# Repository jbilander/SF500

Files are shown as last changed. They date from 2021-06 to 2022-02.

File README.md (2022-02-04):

# SF500
Spitfire 500, A low-end 14 MHz Accelerator with IDE and 4/8 MB fast RAM for the Amiga 500.
***
Heavily inspired by Matthias Heinrichs' CDTV-RAM-IDE board. Many thanks to Matze for sharing his work and letting me open source this project.

https://gitlab.com/MHeinrichs/CDTV-RAM-IDE/

Please note, if you are going to build boards and sell for profit, you will need a consent from Matthias and also from Oliver Kastl if you are going to bundle this software http://aminet.net/package/disk/misc/oktapus with the hardware (ROM-chip).

***

<a href="images/SF500_rev1b_pic1.jpg">
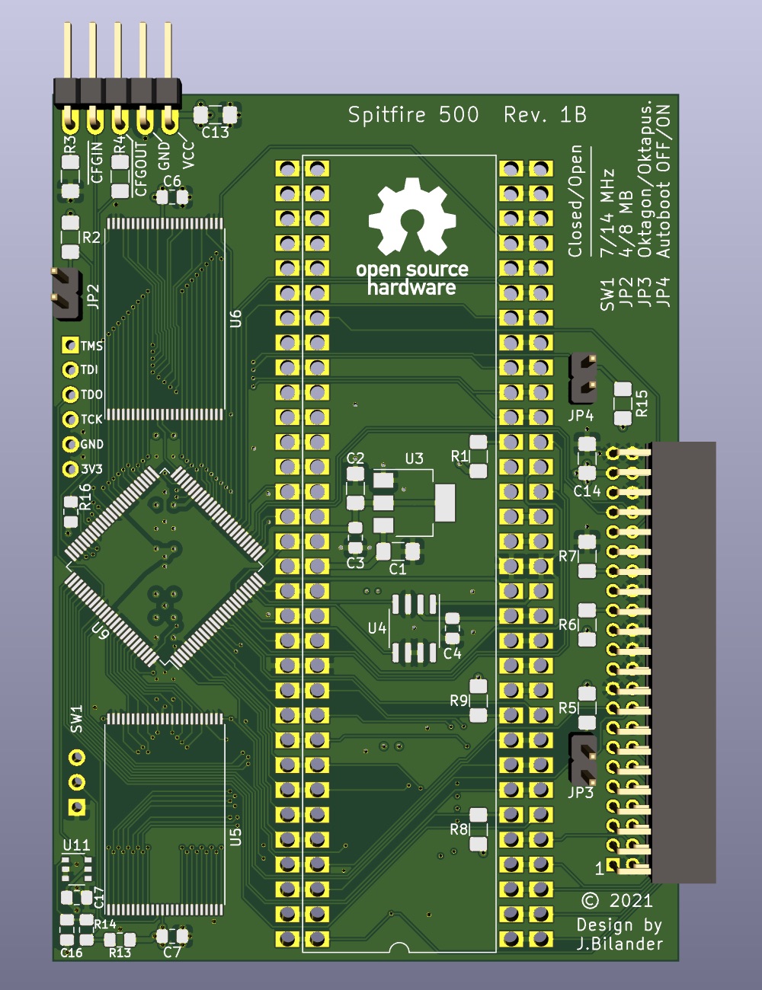
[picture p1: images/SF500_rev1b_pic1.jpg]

</a>
<a href="images/SF500_rev1b_pic2.jpg">
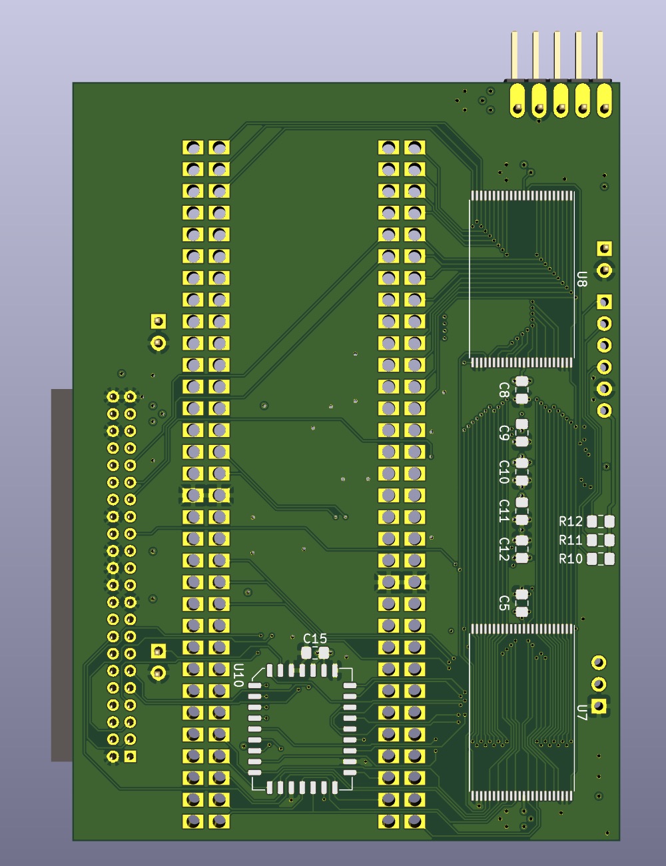
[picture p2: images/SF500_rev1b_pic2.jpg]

</a>

    Board is four layers:
    
    signal (with 3V3-zone)
    power plane (GND)
    power plane (VCC)
    signal

***

Rev. 1B installed in an A500. The 7/14 MHz switch can be easily accessed if hanging out the sidecar port opening of the A500 case. This switch can also be switched while the machine is running.

***

<a href="images/SF500_rev1b_pic3.jpg">
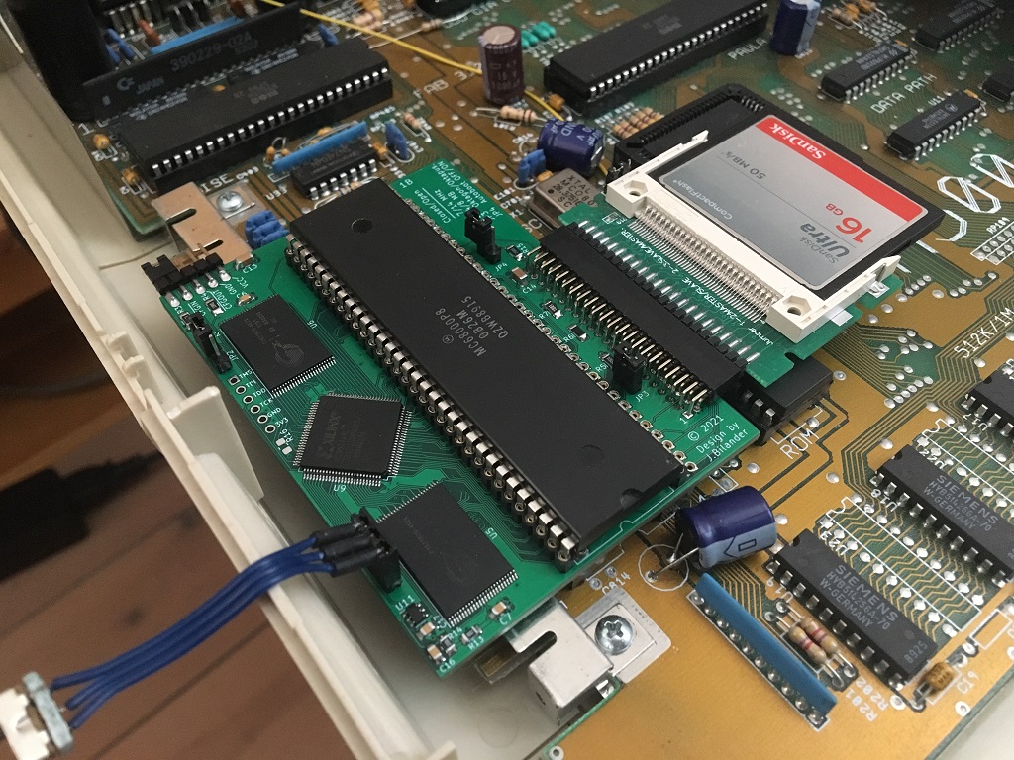
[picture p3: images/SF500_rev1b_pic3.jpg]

</a>
<a href="images/SF500_rev1b_pic4.jpg">
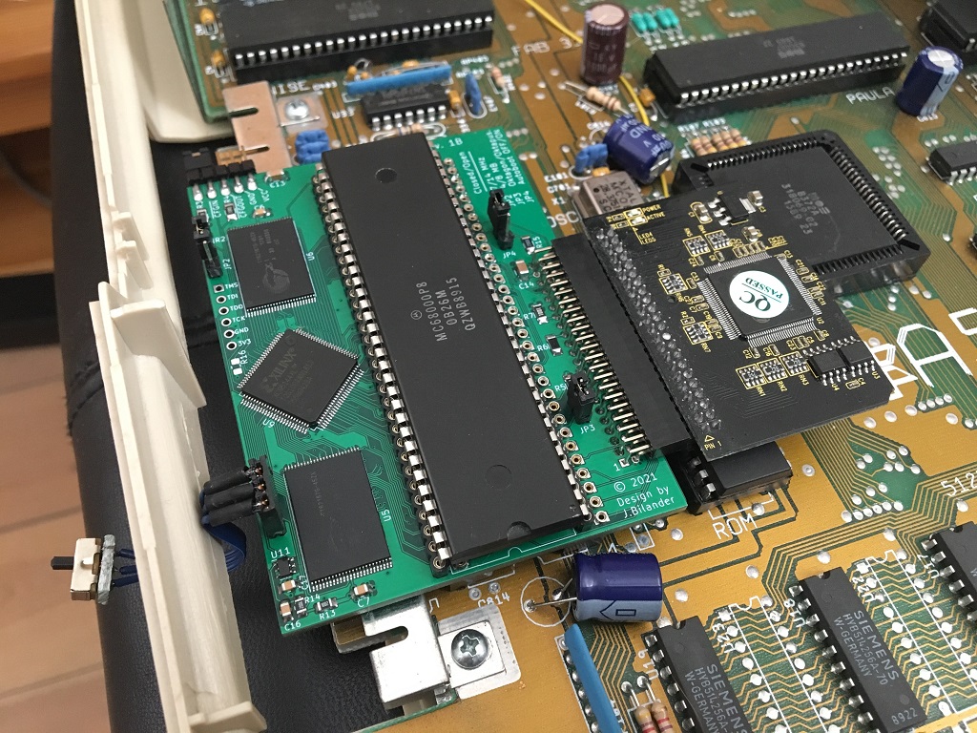
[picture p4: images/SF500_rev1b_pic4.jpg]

</a>

***

Videos: <br /><br />
https://drive.google.com/file/d/1c2K9_kcEqxMMBJBd1aELfbt1fV5XXoU6/view?usp=sharing

SysInfo tests running _oktagon.device_ on WB 1.3 on KS 1.3: <br />
https://drive.google.com/file/d/1rewl8bivpIMPoLze_-Y7_mGYqzTiX6ET/view?usp=sharing

Cold boot running _oktagon.device_ and WB 1.3 on KS 1.3: <br />
https://drive.google.com/file/d/1MFdxnaCo8lNMqMQ6eJMtNUMSsBB8mtb-/view?usp=sharing

Cold boot running _scsi.device v109.3_  (oktapussy) and ClassicWB 3.1 (with 1.3 theme) on KS 3.1: <br />
https://drive.google.com/file/d/1IrmWWG6SJgc65BBj8jGnHebKbp6LAcYa/view?usp=sharing

***

The CPU and the speed-select switch clears the A500 keyboard nicely when installed. Also the CF- or SD-card adapter clears the ROM-chip nicely.

***

<a href="images/SF500_rev1b_pic5.jpg">
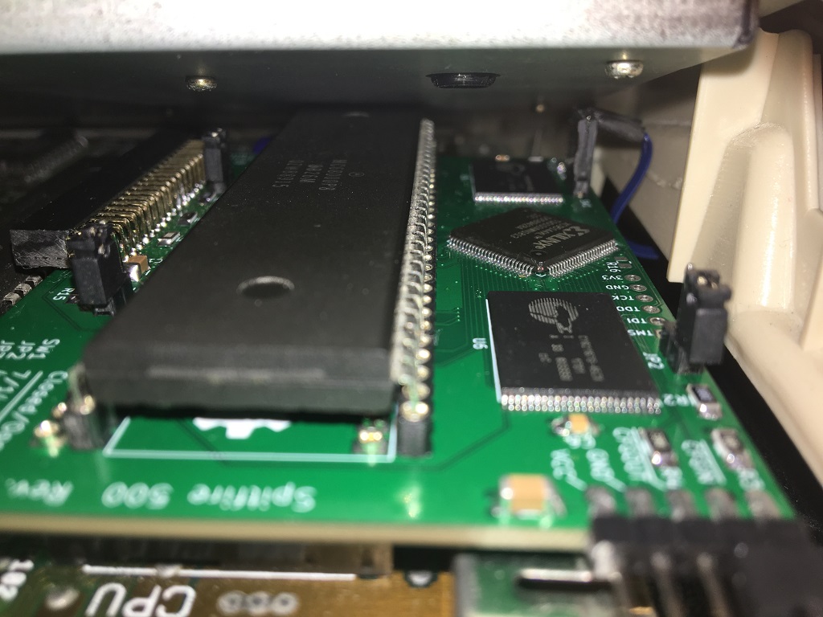
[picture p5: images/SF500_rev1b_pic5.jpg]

</a>
<a href="images/SF500_rev1b_pic6.jpg">
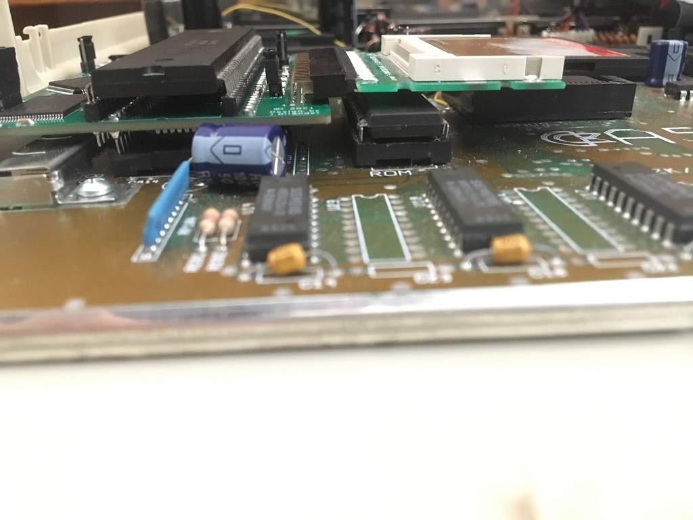
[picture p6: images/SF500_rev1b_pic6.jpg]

</a>

***

### Performance

14 MHz and JP3 Open (scsi.device v109.3):

<a href="images/SF500_rev1b_pic7.jpg">
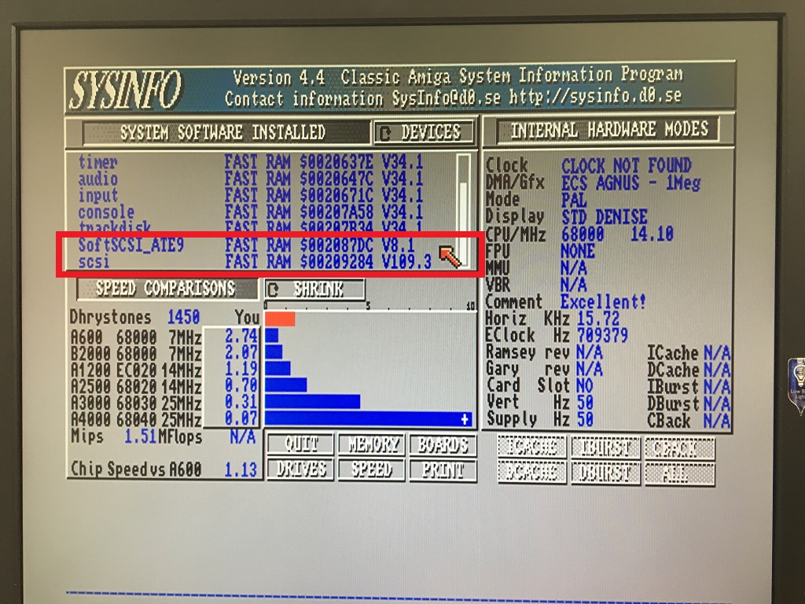
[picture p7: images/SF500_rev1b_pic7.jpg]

</a>
<a href="images/SF500_rev1b_pic9.jpg">
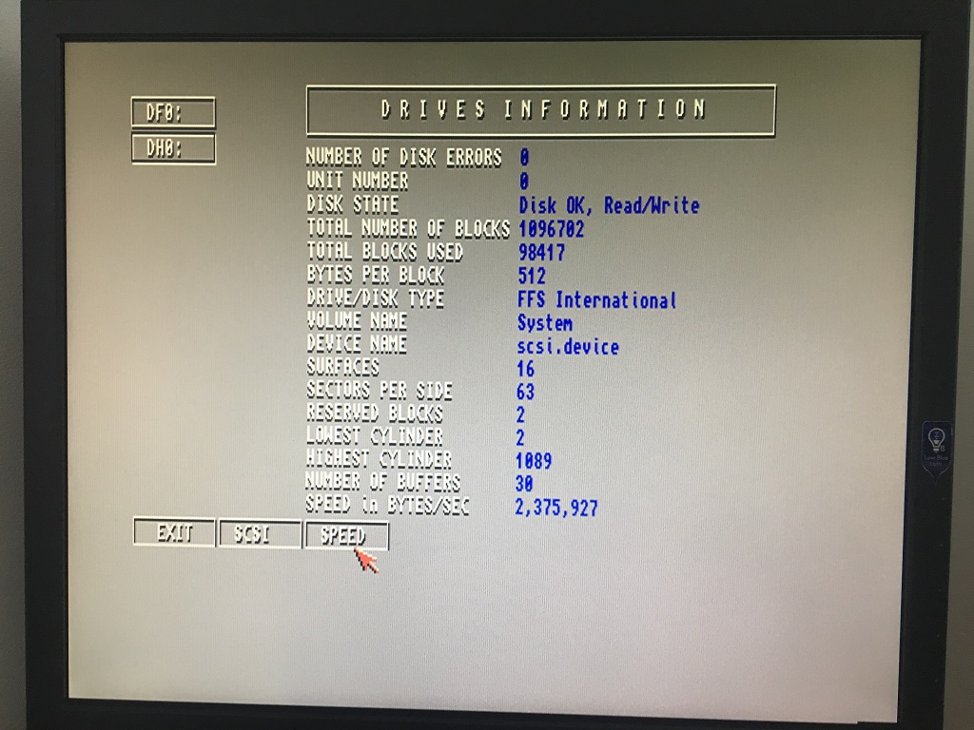
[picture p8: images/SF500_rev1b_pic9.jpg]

</a>

<br />
<br />

14 MHz and JP3 Closed (oktagon.device v6.10):

<a href="images/SF500_rev1b_pic8.jpg">
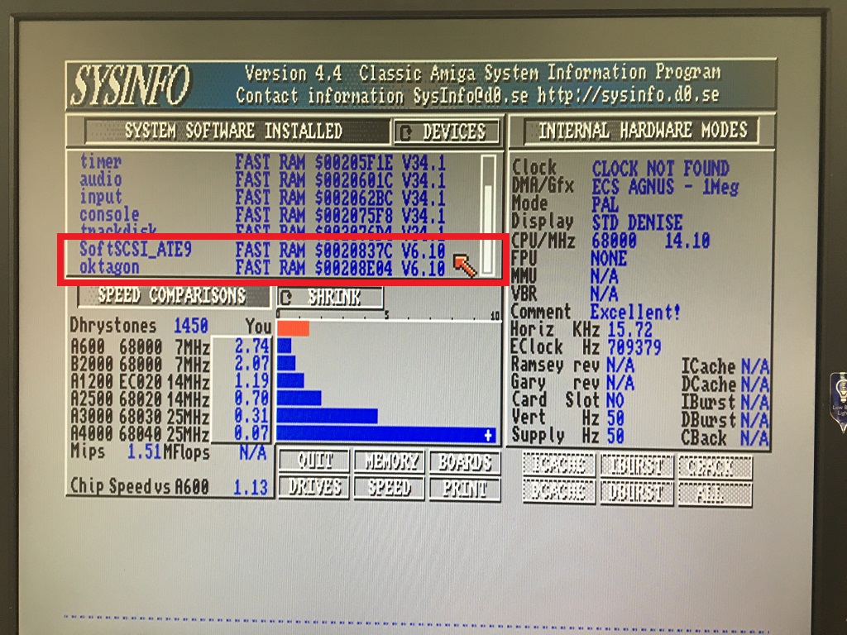
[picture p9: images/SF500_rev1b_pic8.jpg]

</a>
<a href="images/SF500_rev1b_pic10.jpg">
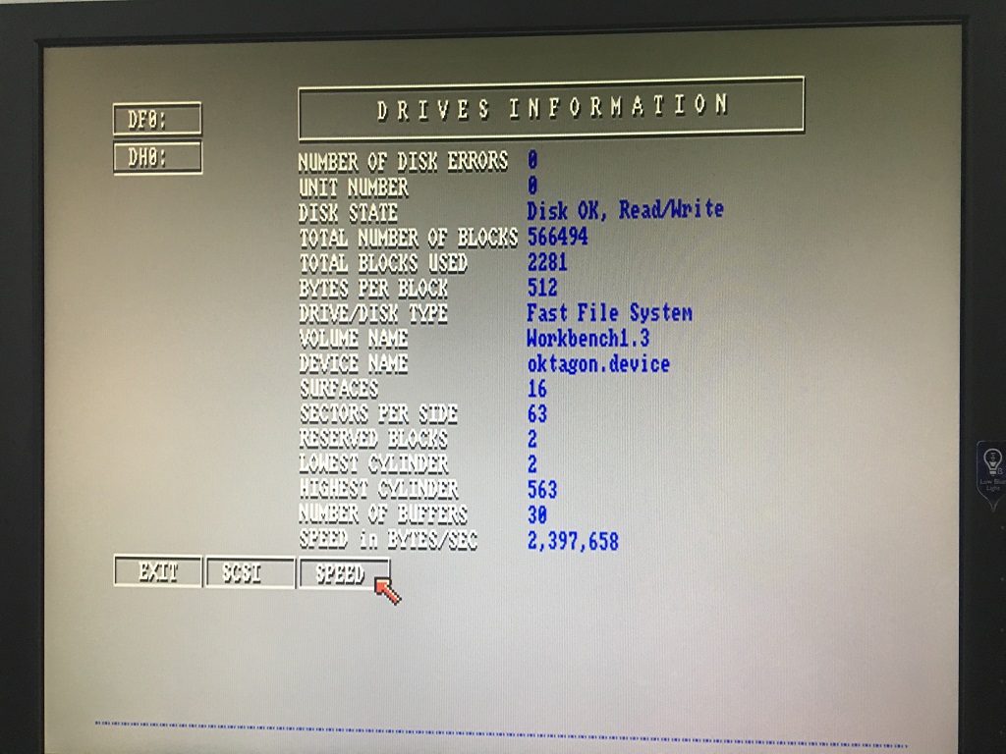
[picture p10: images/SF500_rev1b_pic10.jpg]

</a>

***

Keep in mind Kickstart 1.3 does not have FFS (Fast File System) in ROM, 
so in order to use FFS with 1.3 make a small boot-partition (e.g. ~200 MB) and format it DOS\1, 
not International (DOS\3) or DirCache (DOS\5), and not OFS (DOS\0). For KS 3.1 I would format it FFS International (DOS\3) or perhaps use PFS3. <br /><br />
https://en.wikipedia.org/wiki/Amiga_Fast_File_System <br />

Also, do not forget to set the MaxTransfer to _0x1fe00_ and hit Enter button after typing, then save the setting. This applies to all versions except the new KS 3.2

<a href="images/SF500_rev1b_pic11.jpg">
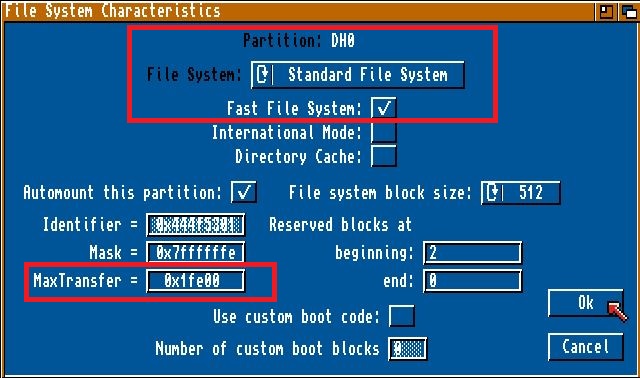
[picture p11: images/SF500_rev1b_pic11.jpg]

</a>
<a href="images/SF500_rev1b_pic12.jpg">
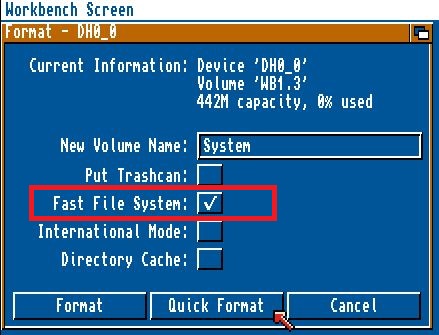
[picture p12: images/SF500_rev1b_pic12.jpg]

</a>
<br />
<br />
Disk's partition and filesystem information should now be stored in the RDB (Rigid Disk Block)
for autoboot to work under WB 1.3 with oktagon.device. 
To install WB 1.3: Copy all content of the WB 1.3 floppy to the newly formatted Drive.

***

### How to Build:

The ROM image to burn to the AM29F040B-70JC chip can be downloaded from here: <br />
https://gitlab.com/MHeinrichs/CDTV-RAM-IDE/-/blob/master/Prog/ATOKTACOMBINED.rom-512.bin

The 64 KB ROM under _Releases_ is a combined ROM I made with the instructions from the textfile [EPROM-Hack_english.txt](https://github.com/jbilander/SF500/blob/main/EPROM-Hack_english.txt) in this repo (also available in German).
It is 060-compatible too, not that it makes any difference for this accelerator that uses a 68000 or 68010 CPU.

Burning any of the two ROM:s above will work with this Accelerator (SF500).

The last version of the Oktagon2008 from BSC is 6.12 - but still reports as 6.10. As far as I know, only the boot code has changed to be compatible with the 68060. The actual driver is still 6.10.

Remember to Program the chip BEFORE you solder it down to the PCB. Do not byteswap if you are using a TL866II-Plus or similar programmer on Windows/Intel-arch, these parts are 8-bit so there is no concept of byte swapping.

***

Soldering: Start with all the surface mounts and then TH. I usually start with the Voltage regulator and verify the 3V3. Then the CPLD and verify JTAG-connection, doing a boundary scan with ISE-Impact. No need to solder a pin header to the JTAG connector on the PCB, just hold the connector in position and press gently. It should also be possible to use a Raspberry Pi and the program _xc3sprog_. Optionally you can put 10k or 4.7k pull-ups on R10-R12 (TMS,TDI,TCK) if you have problems connecting to the CPLD, those are 3V3 pull-ups so shouldn't damage anything using GPIO from a RPi. VCC is +5V and can be supplied through a typical usb phone-charger or similar, check polarity BEFORE you plug it in.

***

<a href="images/SF500_rev1b_pic13.jpg">
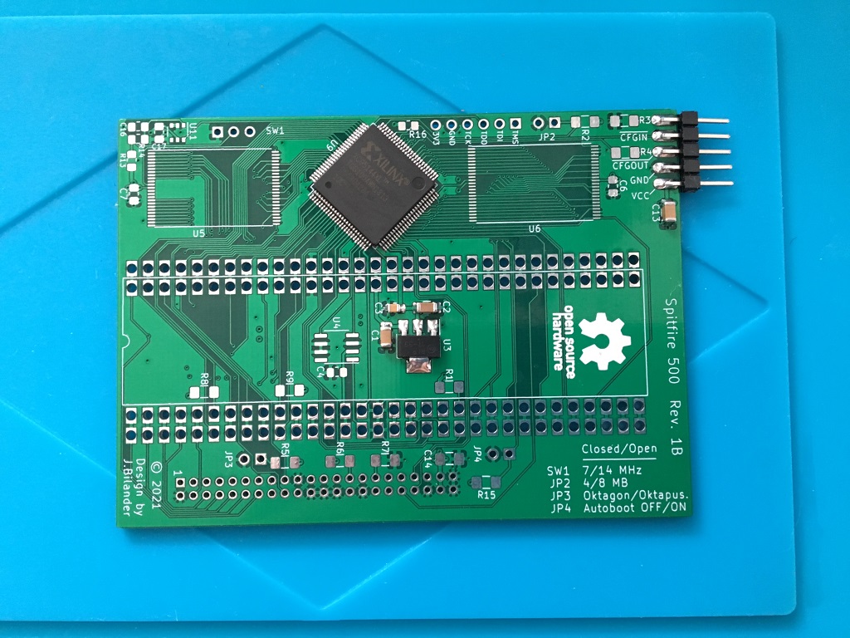
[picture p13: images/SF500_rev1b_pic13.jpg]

</a>
<a href="images/SF500_rev1b_pic14.jpg">
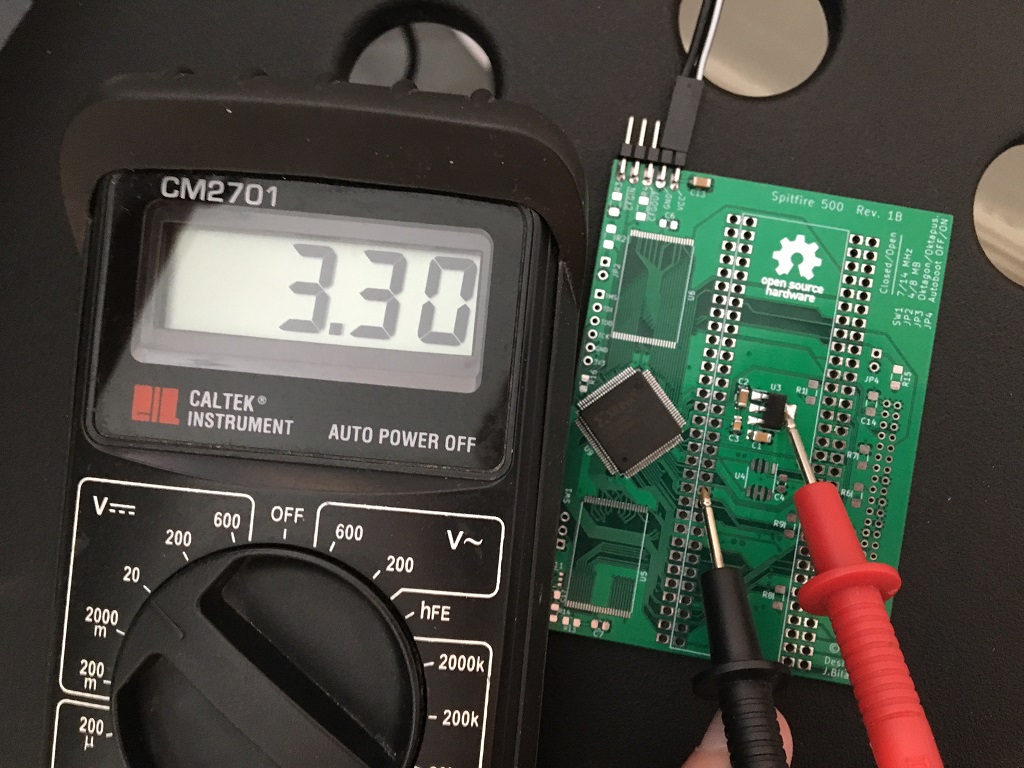
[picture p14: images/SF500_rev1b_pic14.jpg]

</a>
<br />
<a href="images/SF500_rev1b_pic15.jpg">
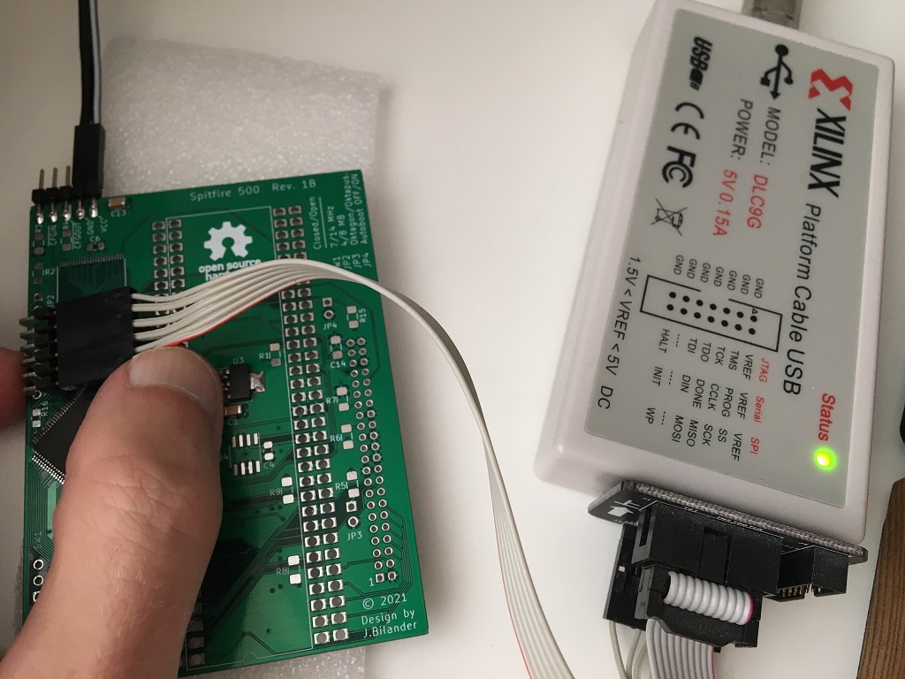
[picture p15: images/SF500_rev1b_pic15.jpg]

</a>
<a href="images/SF500_rev1b_pic16.jpg">
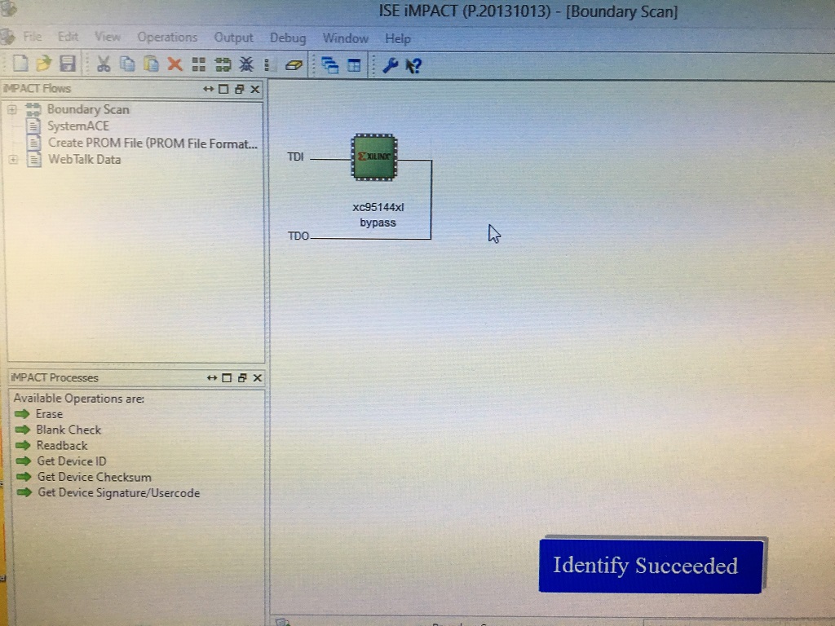
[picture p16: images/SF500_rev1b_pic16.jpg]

</a>

***

Using some kapton tape can help to hold the chip in place while tacking it down to get everything aligned properly. For the ROM-chip I pre-tin the pads and then use hot air rework station to solder it in place.

***

<a href="images/SF500_rev1b_pic17.jpg">
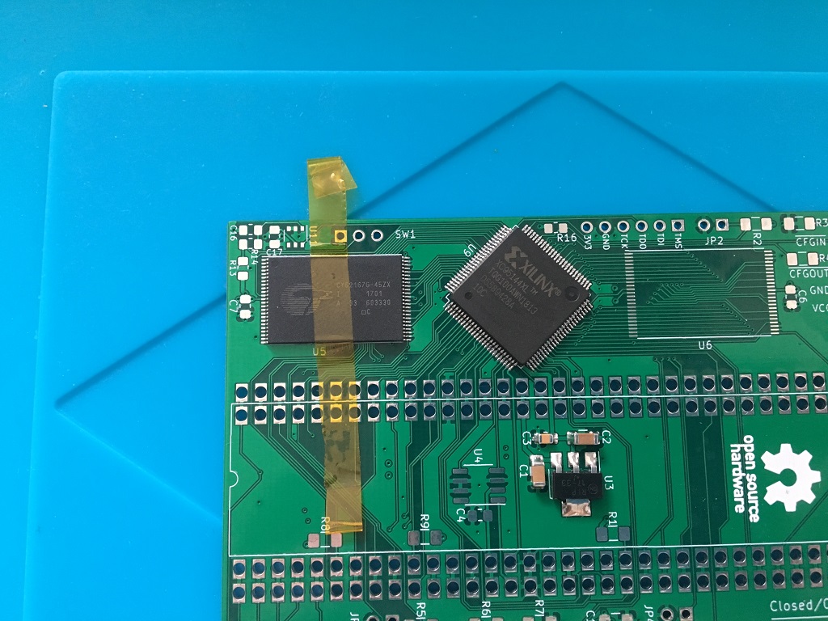
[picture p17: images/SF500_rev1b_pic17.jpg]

</a>
<a href="images/SF500_rev1b_pic18.jpg">
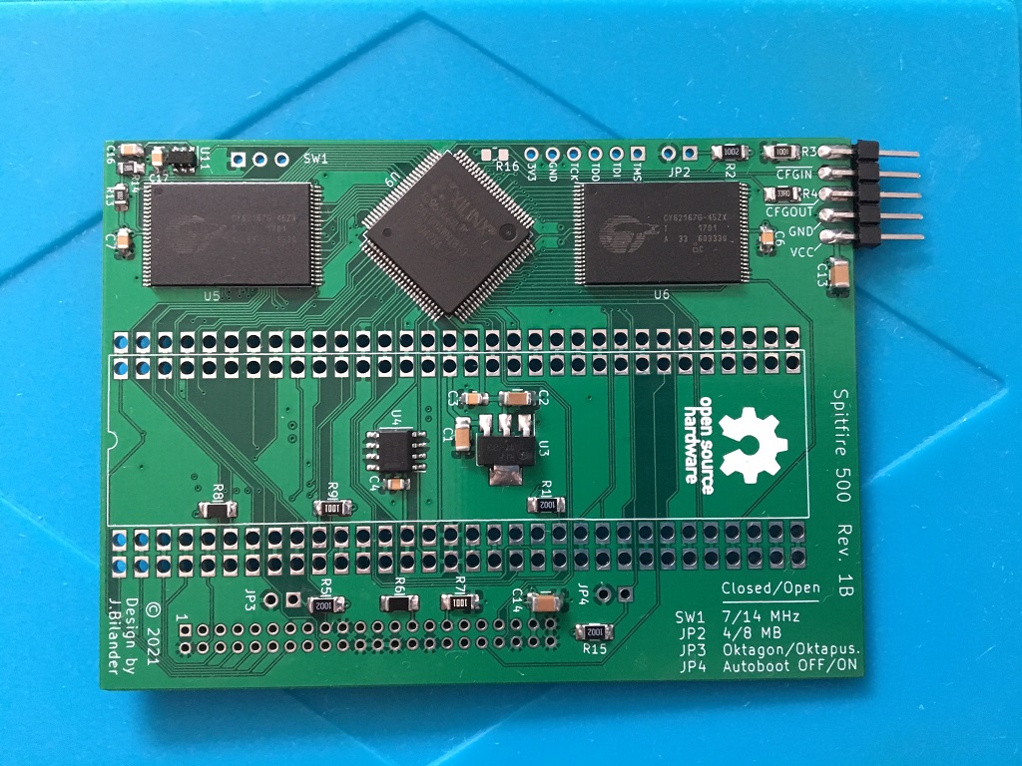
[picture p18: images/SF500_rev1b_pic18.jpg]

</a>
<br />
<a href="images/SF500_rev1b_pic19.jpg">
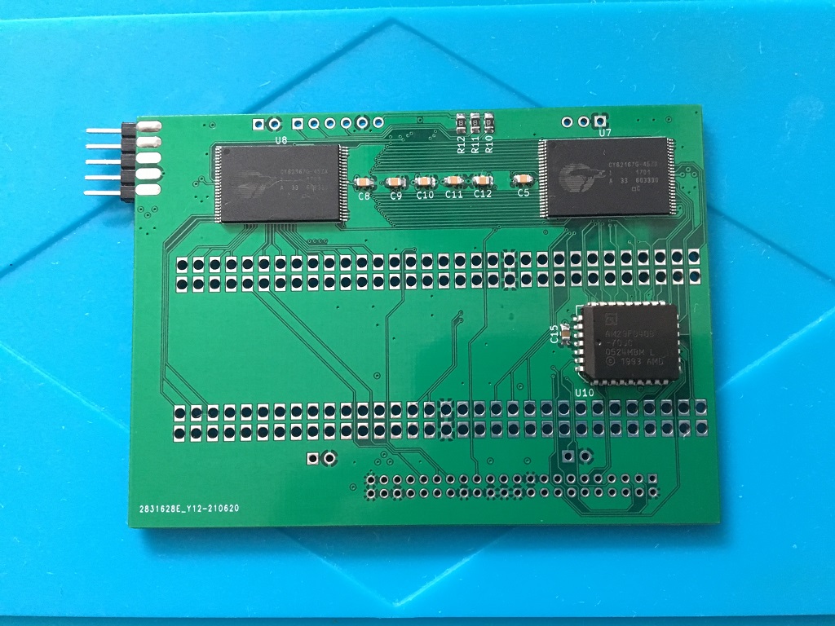
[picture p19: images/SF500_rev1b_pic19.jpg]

</a>
<a href="images/SF500_rev1b_pic20.jpg">
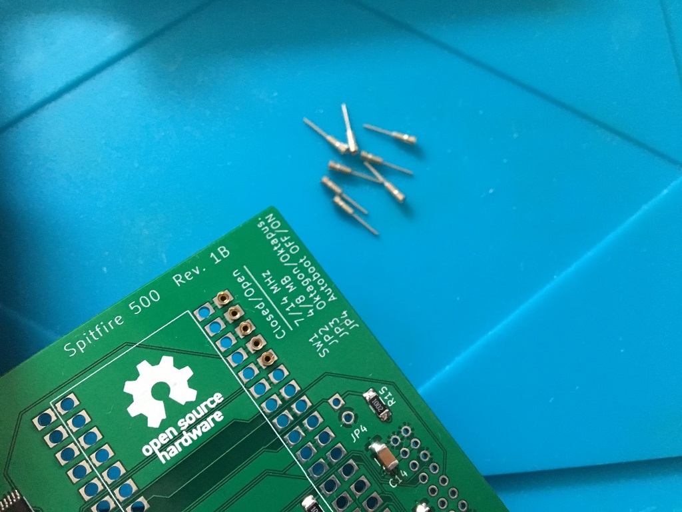
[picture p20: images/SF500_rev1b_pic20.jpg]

</a>

***

When all the surface mount components are done it's time for the TH-pins. I use an old 68k CPU as a jig and a piece of pin strip on the other side to align the pins while soldering them in position. Press ontop the CPU somewhat at the same time when soldering for a great result.

***

<a href="images/SF500_rev1b_pic21.jpg">
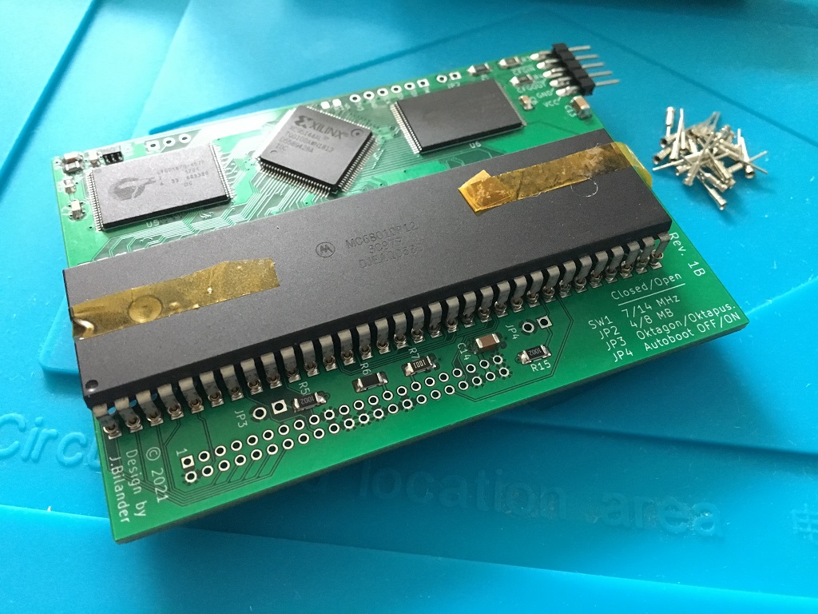
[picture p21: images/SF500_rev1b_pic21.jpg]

</a>
<a href="images/SF500_rev1b_pic22.jpg">
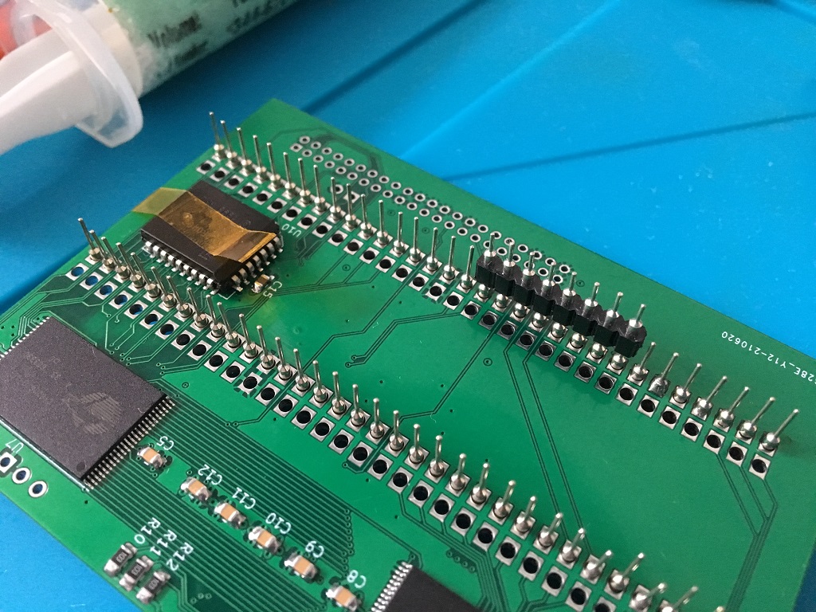
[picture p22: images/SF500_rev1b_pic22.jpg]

</a>

***

I used a 1.2mm thick PCB as a spacer while soldering the 44-pin IDE connector in place. This because it'll clear the Kickstart ROM chip better if the connector and hence the adapter is positioned a little higher up. The 44-pinout on the PCB is deliberately flipped/designed so that you can plug the CF or SD-adapter directly to the angled-connector the "right" way, no ribbon cable and no buffering is used.

***

<a href="images/SF500_rev1b_pic23.jpg">
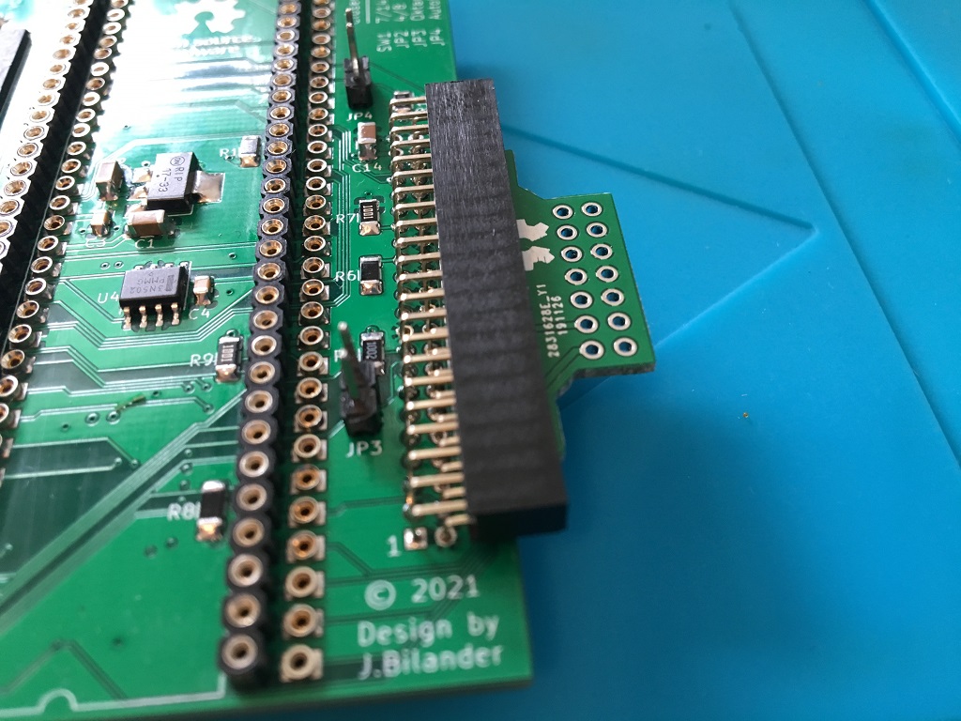
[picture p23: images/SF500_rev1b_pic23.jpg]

</a>
<a href="images/SF500_rev1b_pic24.jpg">
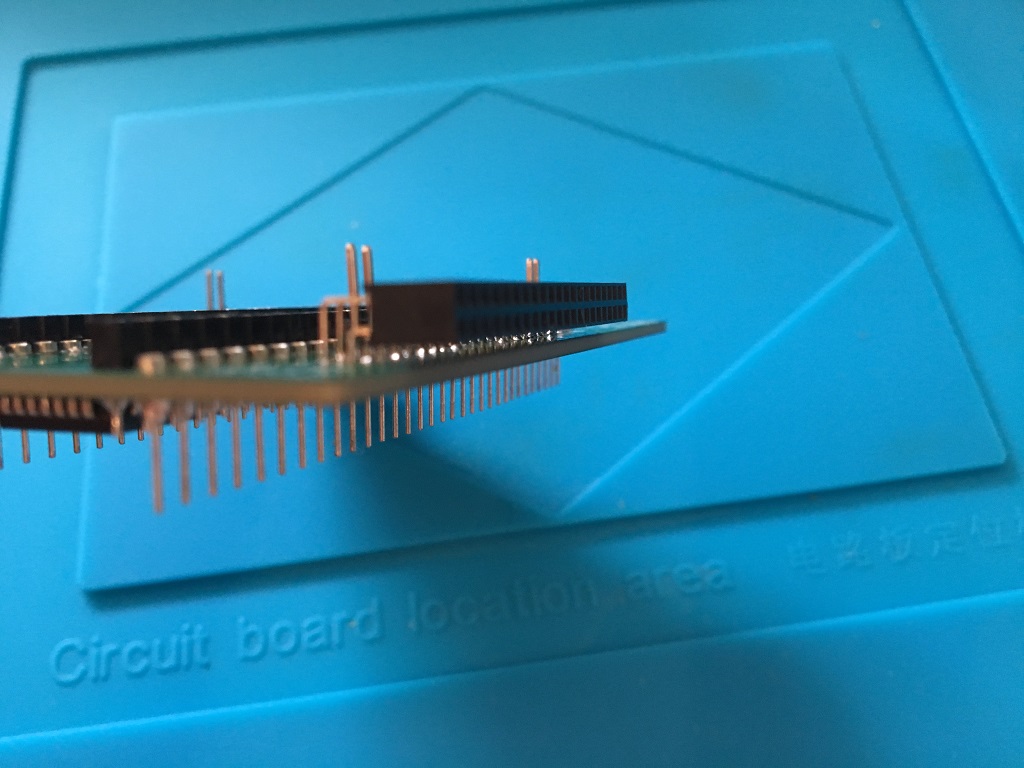
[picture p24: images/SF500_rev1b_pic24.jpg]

</a>
<br />
<a href="images/SF500_rev1b_pic25.jpg">
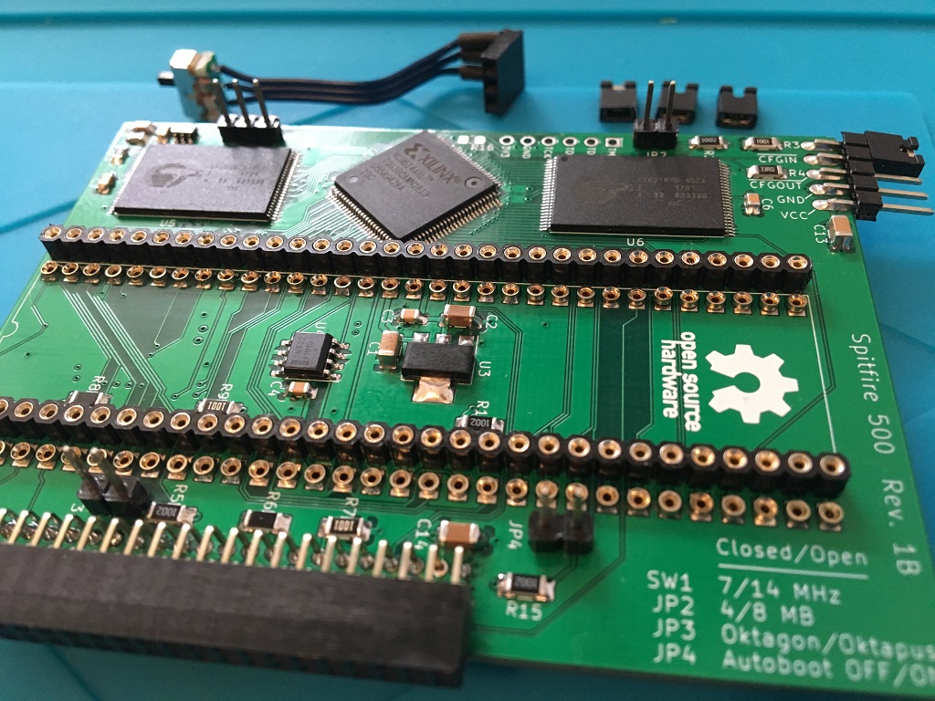
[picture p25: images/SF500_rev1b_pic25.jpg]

</a>
<a href="images/SF500_rev1b_pic26.jpg">
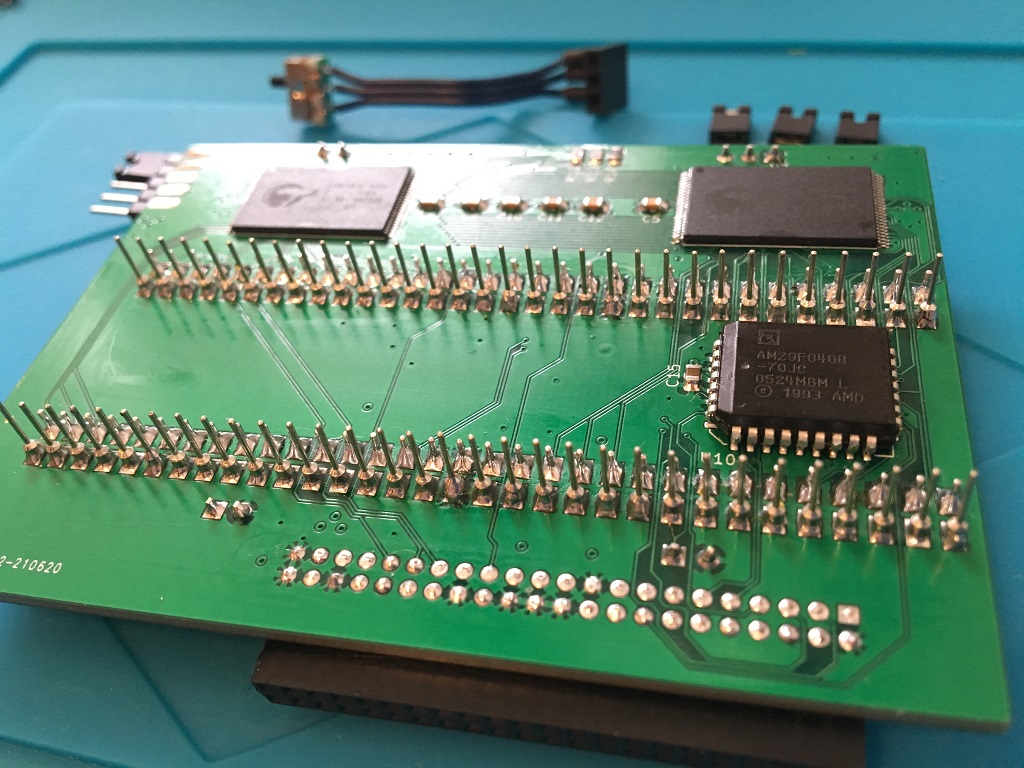
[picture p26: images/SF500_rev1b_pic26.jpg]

</a>

***

The final result. The mini-slide switch can optionally be soldered directly to the PCB if you prefer it that way. Only two pins are actually used, it's a normal two pin jumper with default pull-up, the third pin/hole is not connected and is only there to allow for soldering the mini-slide switch directly onto the PCB.

***

<a href="images/SF500_rev1b_pic27.jpg">
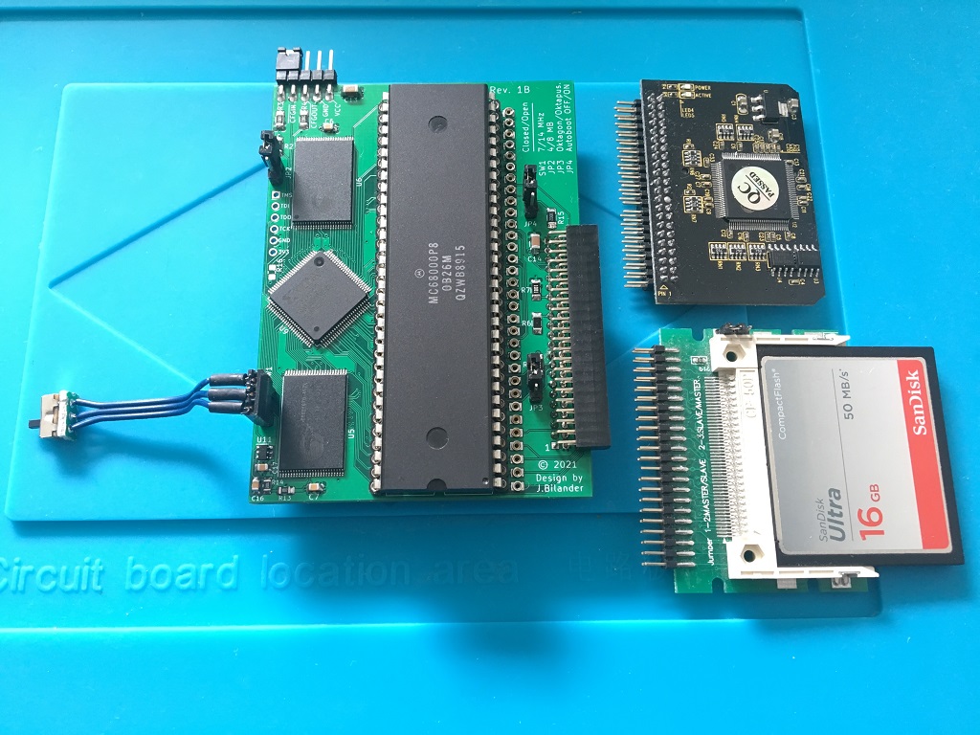
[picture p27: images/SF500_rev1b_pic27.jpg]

</a>

***

Programming can now be done either this way...

***

<a href="images/SF500_rev1b_pic28.jpg">
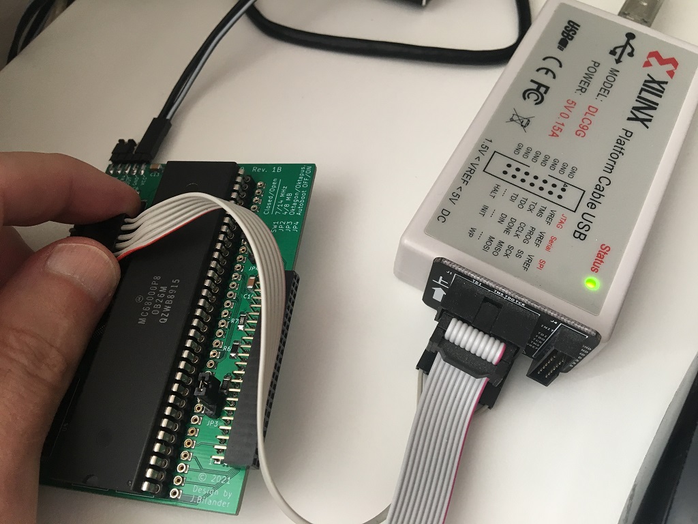
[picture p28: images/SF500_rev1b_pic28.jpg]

</a>
<a href="images/SF500_rev1b_pic29.jpg">
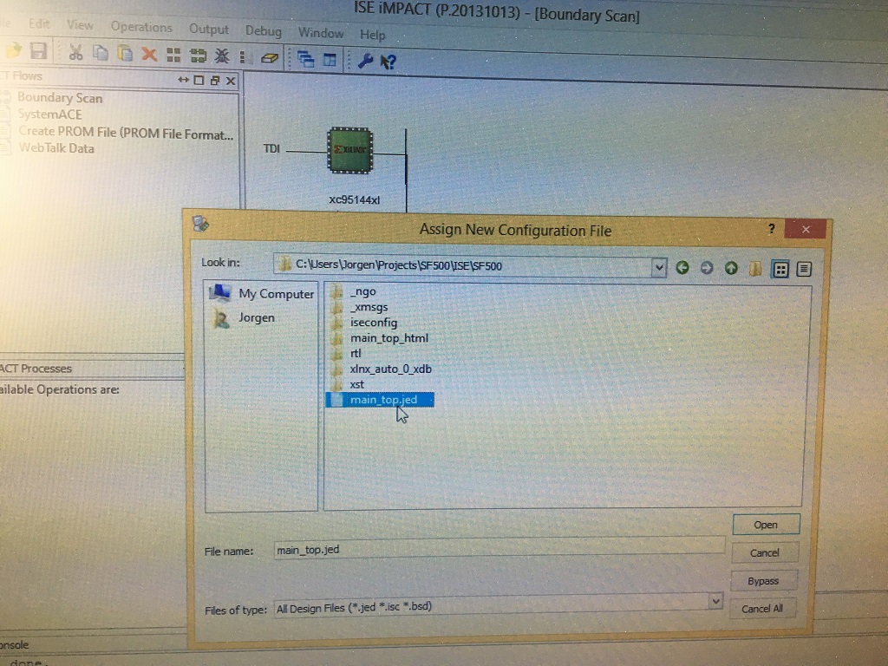
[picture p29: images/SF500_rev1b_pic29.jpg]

</a>
<br />
<a href="images/SF500_rev1b_pic30.jpg">
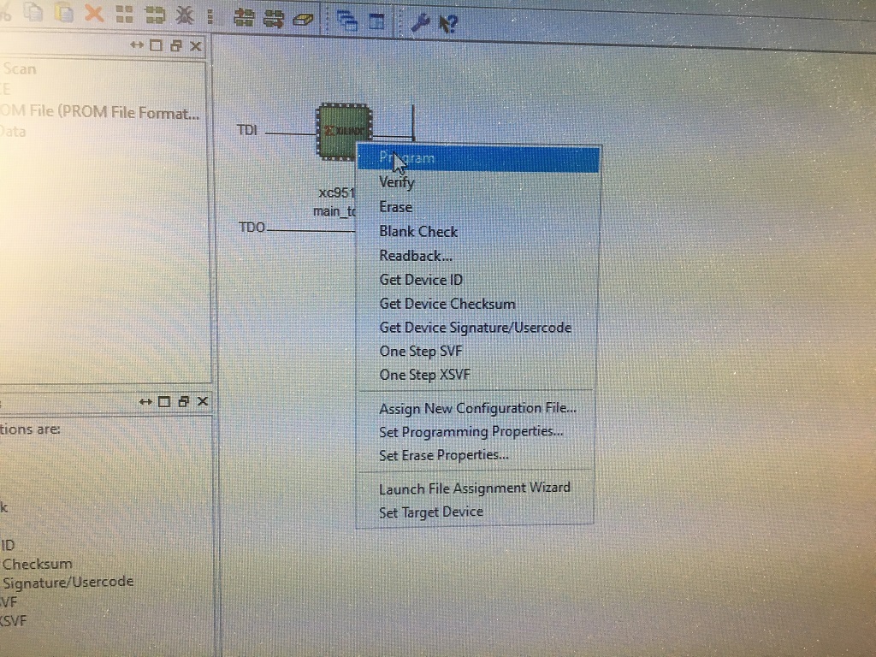
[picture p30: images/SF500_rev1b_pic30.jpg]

</a>
<a href="images/SF500_rev1b_pic31.jpg">
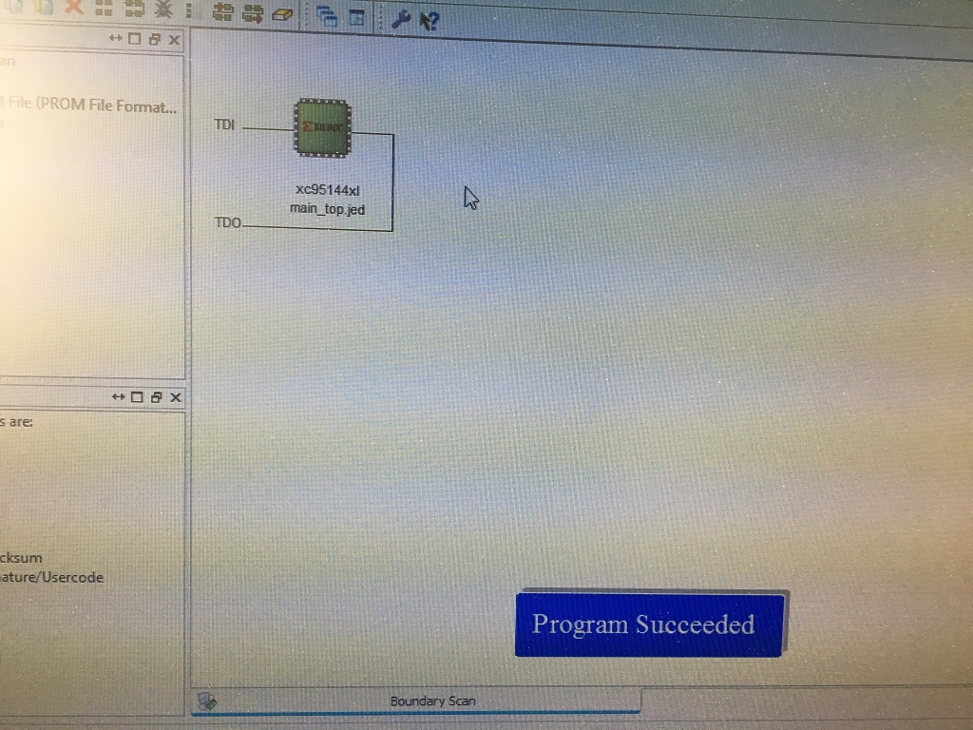
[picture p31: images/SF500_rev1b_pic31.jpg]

</a>

***

...or like in picture below...it requires the Amiga PSU to be turned ON to provide +5V to the Accelerator, do not connect any external +5V here:

***

<a href="images/SF500_rev1a_pic4.jpg">
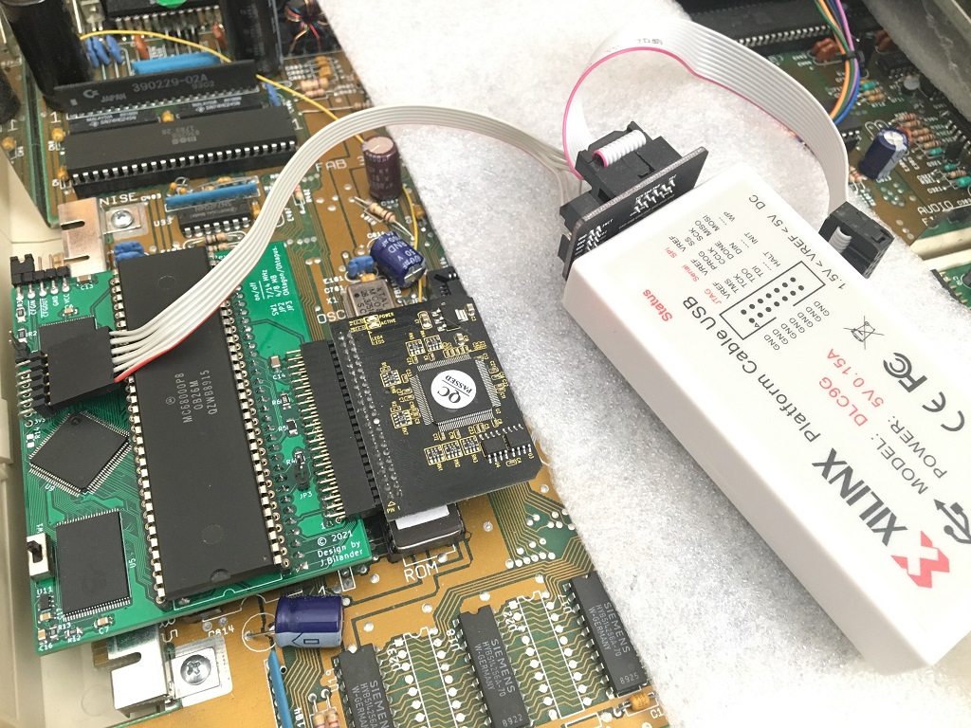
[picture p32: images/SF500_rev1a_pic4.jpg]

</a>

***

Jumpers:

    /CFGIN = This jumper is to activate autoconfig (active low with 1k pull-down resistor R3). No jumper here means no RAM nor IDE will be autoconfigured. 
    SW1 = CPU speed toggle between 7 or 14 MHz, default 10k pull-up means 14 MHz
    JP2 = Selects between 4 or 8 MB fast ram autoconfig, 8 MB requires U7,U8 populated too.
    JP3 = Selects between IDE driver oktagon.device or scsi.device_v109.3 (oktapussy)
    JP4 = Selects between Autoboot or Not, jumper Closed means autoconfigure will not load the ROM-vector (the JP3-selected driver).

***

Synthesis Summary:

<a href="images/SF500_rev1b_synthesis_summary.jpg">
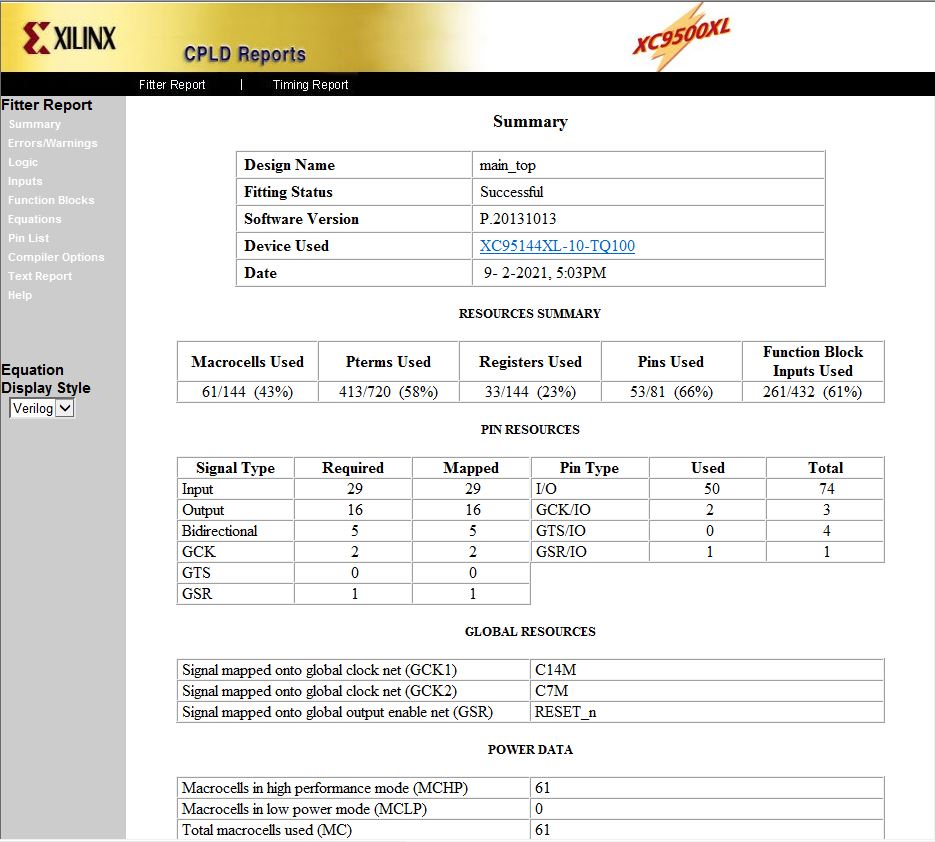
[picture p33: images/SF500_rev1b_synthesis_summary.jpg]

</a>

Zipped JED-file (_main_top.jed_) available under _Releases_

New firmware released 2021-12-22 that supports DMA from A590, available under _Releases_

***

### SF500 and A590
With the updated firmware it's now possible to use an A590 (on the A500 expansion edge) togheter with a SF500.
<br />
You will need to solder/connect a jumper-wire from the CFGOUT-goldfinger-pad and run it to the CFGIN-pin on the SF500. This will asure that there will be no conflict during AutoConfig cycles. They will be daisy-chained meaning the A590 configures first and the SF500 is second in line.

<a href="images/SF500_and_A590_pic1.jpg">
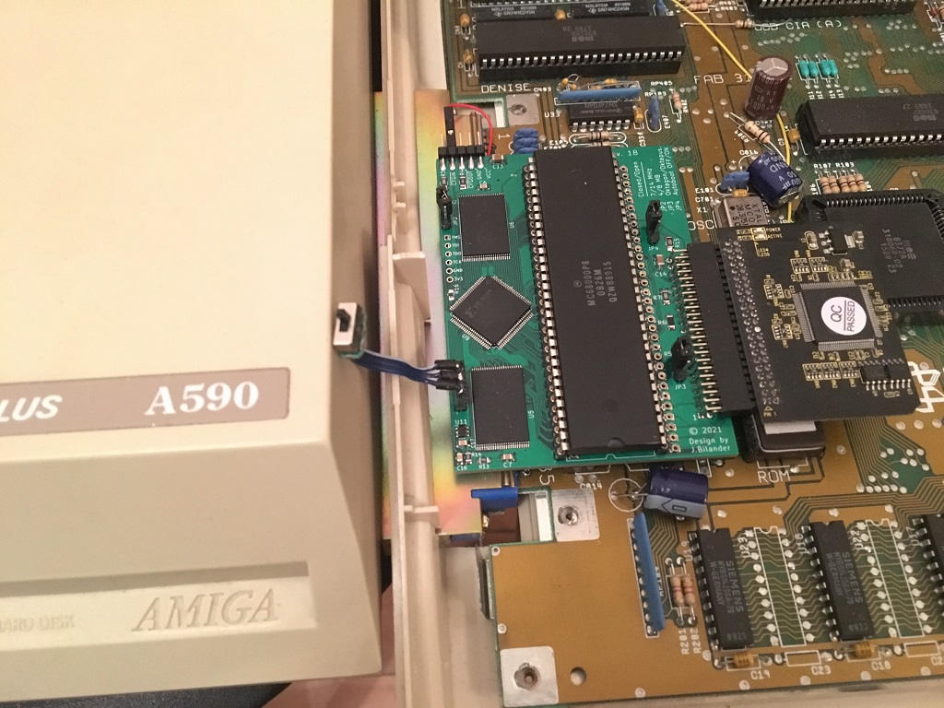
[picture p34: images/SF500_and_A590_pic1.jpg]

</a>
<a href="images/SF500_and_A590_pic2.jpg">
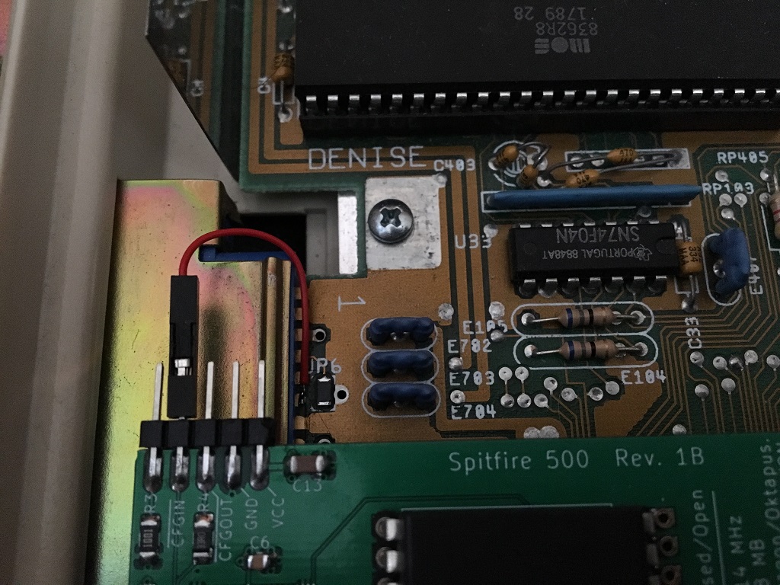
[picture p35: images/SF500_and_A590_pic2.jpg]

</a>

***

Having the A590 jumper set to enable onboard memory (2MB in picures below) is not optimal in this case since that memory will automatically be used first by the system. You will have to set the jumper (JP2) to _ON_ (4MB) on the SF500 in this scenario but as you can see only 0.84 mips here:

<a href="images/SF500_and_A590_pic3.jpg">
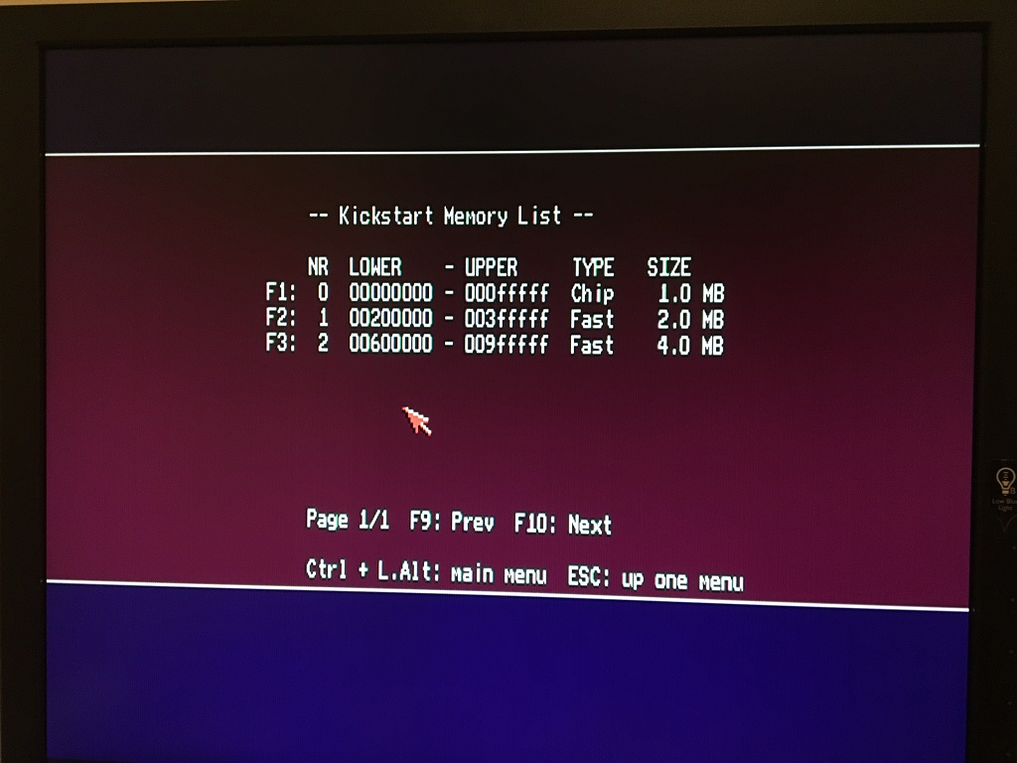
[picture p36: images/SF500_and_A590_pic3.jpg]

</a>
<a href="images/SF500_and_A590_pic4.jpg">
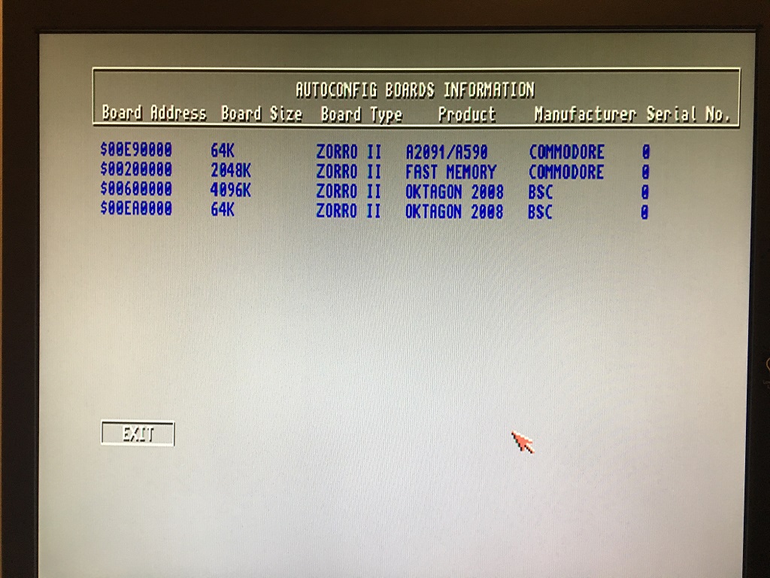
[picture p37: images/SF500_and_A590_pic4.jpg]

</a>
<a href="images/SF500_and_A590_pic5.jpg">
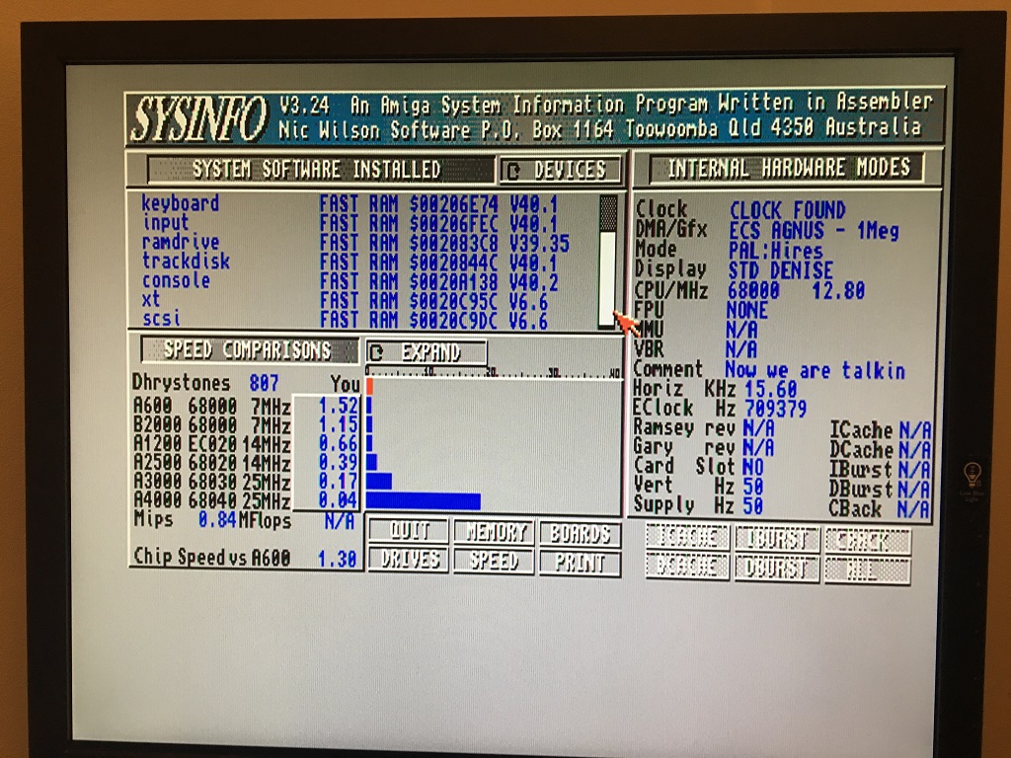
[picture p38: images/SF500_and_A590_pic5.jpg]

</a>

***

In this case it's much better to set the A590 jumper to _Amnesia_ and hence "only" use the 4MB or 8MB from the SF500. Don't worry the A590 can then DMA (Direct Memory Access) into that memory:

***

<a href="images/SF500_and_A590_pic6.jpg">
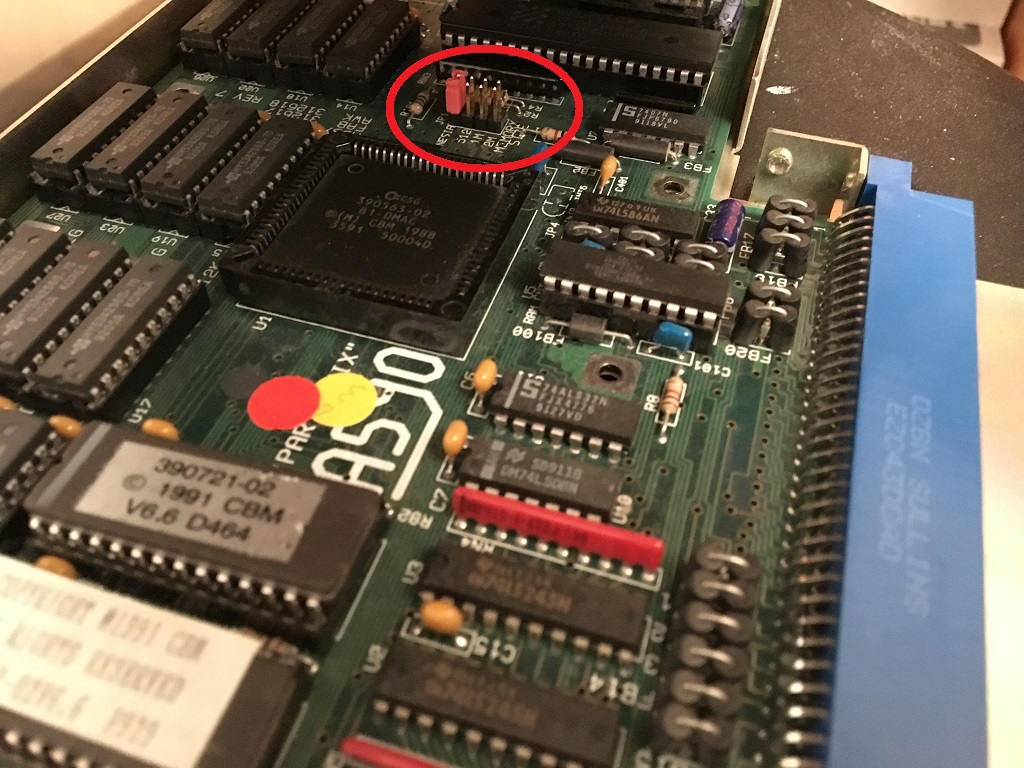
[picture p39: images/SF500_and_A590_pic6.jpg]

</a>
<a href="images/SF500_and_A590_pic7.jpg">
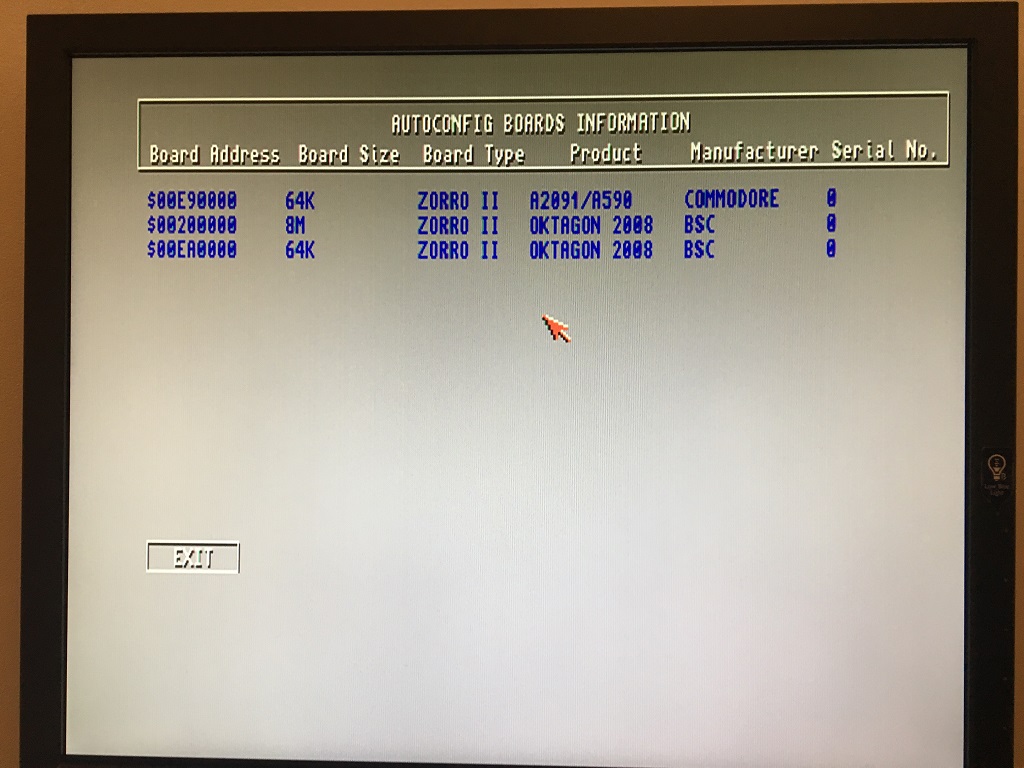
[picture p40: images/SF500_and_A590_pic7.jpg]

</a>

***

With the SF500 set to _Amnesia_ we get the full performance at 14 MHz and we can use the Hard Drive in the A590 either to boot from or just as a second harddrive for storage or backup (this depends on boot prio setting). Both the Oktagon.device and the Oktapussy scsi.device can co-exist with the A590 driver. As you can see the oktapussy driver takes the name _2nd_ scsi device here:

***

<a href="images/SF500_and_A590_pic8.jpg">

</a>
<a href="images/SF500_and_A590_pic9.jpg">

</a>
<br />
<a href="images/SF500_and_A590_pic10.jpg">

</a>
<a href="images/SF500_and_A590_pic11.jpg">

</a>

***

Changing boot priority in HDToolBox let us select which drive to boot from. Please note, I used prio 10 here but if you still want the DF0 floppy drive as the first device (you probably will) then you can't put in a number above 5. Keep it below 5 since DF0 has boot priority 5 by default, this was just for testing, remember to press Enter after entering the new value in the box and then hit the _Save Changes to Drive_ button before you do a reboot.

<a href="images/SF500_and_A590_pic12.jpg">

</a>
<a href="images/SF500_and_A590_pic13.jpg">

</a>

***

A short video showing boot from A590 in _Amnesia_ mode and copying a 2.2 MB file from the SF500 IDE drive to the A590 XT drive. <br /><br />
https://drive.google.com/file/d/1oLW0H9GmMaRv7rbYKLQVwRg4RvrDyU3E/view?usp=sharing
<br /><br />
Here a short video booting from the SF500 IDE drive (with higher boot prio set) than the A590 (still in _Amnesia_ mode). The A590 harddrive is automatically mounted and available to the system after startup:<br /><br />
https://drive.google.com/file/d/13qs9DawRrVdHNif9vCZlh3xlq8YgDj_f/view?usp=sharing

***

BOM Rev. 1B
---------
Position  | Name/Value   | Package | Notes
-|-|-|-|
U1 | 64Pcs socket pins for Round Plug 0.5mm Diameter | 100Pcs | IC Leads Receptacle, gold or nickel plated, used as TH Pin Header. https://www.aliexpress.com/item/1005002830101899.html
U2 | CPU Socket, 2 x 32 Female Pin Header 2.54mm pitch | 2 x Single Row 40Pin | Round Female Pin Header gold or nickel plated machined pins.
U3 | Voltage Regulator 3.3V, LM1117-3.3 or AMS1117-3.3 | SOT-223 | 3.3V 1A Low Drop-Out (LDO) Voltage regulator.
U4 | NB3N502 - 14 MHz to 190 MHz PLL Clock Multiplier | SOIC-8 | PLL with CLKOUT and at the same time output the input aligned reference clock signal (REF).
U5-U6 | 2 x CY62167G-45ZXI or 2 x CY62167ELL-45ZXI | 48-pin TSOP-I configurable as 1M × 16 or 2M × 8 SRAM |  First 4 MB. Cost $3 / Pcs from here https://www.aliexpress.com/item/1005003256658439.html (verified ok)
U7-U8 | 2 x CY62167G-45ZXI or 2 x CY62167ELL-45ZXI | | (Optional) Second 4 MB.
U9 | XC95144XL-TQ100 | TQFP-100_14x14mm_P0.5mm | IC Xilinx CPLD 144MC 10NS 100TQFP, XC95144XL-10TQG100C
U10 | 29F040 or 29F010 | PLCC-32_11.4x14.0mm_P1.27mm | e.g. AM29F040B-70JC or AS29CF010-55CCIN
U11 | 74HCT2G14 | TSOP-6 | Dual inverting Schmitt trigger
R1 | 10k | 1206 | /VPA Pull-up resistor
R2 | 10k | 1206 | JP2 Pull-up resistor (P74)
R3 | 1k | 1206 | /CFGIN Pull-down resistor (P70)
R4 | 33 Ohm or 0 Ohm | 1206 | (Optional) /CFGOUT series resistor (P68)
R5 | 10k | 1206 | JP3 Pull-up resistor (Line A15 ROM)
R6 | 4.7k | 1206 | IDE_IORDY Pull-up resistor (P12)
R7 | 1k | 1206 | IDE_IRQ Pull-down resistor (P27)
R8 | 4.7k | 1206 | /AS_CPU Pull-up resistor (P79)
R9 | 1k | 1206 | /DTACK_CPU Pull-up resistor (P13)
R10 | 4.7k or 10k | 0805 | (Optional) TMS 3.3V Pull-up resistor (P47)
R11 | 4.7k or 10k | 0805 | (Optional) TDI 3.3V Pull-up resistor (P45)
R12 | 4.7k or 10k | 0805 | (Optional) TCK 3.3V Pull-up resistor (P48)
R13 | 10k | 0805 | SW1 Pull-up resistor debounce circuit (P76)
R14 | 10k | 0805 | resistor in (RC) debounce circuit
R15 | 10k | 1206 | JP4 Pull-up (P67)
R16 | 4.7k or 10k | 0805 | (Optional) CFGIN Pull-up (P70)
C1 | 10uF | 1206 | capacitor for Voltage regulator
C2 | 10uF | 1206 | capacitor for Voltage regulator
C3 | 0.1uF = 100nF | 0805 | capacitor for Voltage regulator
C4 | 0.1uF = 100nF | 0805 | decoupling capacitor for U4 (PLL)
C5-C6 | 0.1uF = 100nF | 0805 | decoupling capacitors for U5-U6 (first 2 x SRAM)
C7-C8 | 0.1uF = 100nF | 0805 | decoupling capacitors for U7-U8 (if populated, second 2 x SRAM)
C9-C12 | 0.1uF = 100nF | 0805 | decoupling capacitors for U9 (CPLD)
C13 | 10uF | 1206 | capacitor for VCC-pin
C14 | 10uF | 1206 | capacitor for IDE VCC-pin
C15 | 0.1uF = 100nF | 0805 | decoupling capacitor for U10 (ROM)
C16 | 0.1uF = 100nF | 0805 | capacitor in (RC) debounce circuit (SW1)
C17 | 0.1uF = 100nF | 0805 | decoupling capacitor for U11 (Schmitt trigger inverter)
J1 | JTAG Pin Header 2.54mm pitch | Single row 6pin | (Optional) Pressing JTAG-header pins against holes while programming is enough.
J2 | External Pin Header 2.54mm pitch | Single row 5pin angled or straight | 2.54mm Jumper on CFGIN-pin needed for enable Autoconfig unless daisy chained.
SW1 (J3) | 3Pin Header 2.54mm pitch | Single row 3pin | Pin header with jumper select 7/14MHz or On-Off mini slide switch SS12D00 3pin 1P2T 2 Position toggle switch. Handle length: 3mm-6mm
J4 | 2.0mm Pitch Right Angle IDE-socket | Double Row (2 x 22) Female 44pin header socket | 2 x 25 or 2 x 40, pull pin 45, 46 using a plier and cut with a hacksaw = Pin header 2 x 22. https://www.aliexpress.com/item/4001286548060.html

***

Happy Hackin' 

***

[][cc-by-sa]

This work is licensed under a
[Creative Commons Attribution-ShareAlike 4.0 International License][cc-by-sa].

[][cc-by-sa]

[cc-by-sa]: http://creativecommons.org/licenses/by-sa/4.0/
[cc-by-sa-image]: https://licensebuttons.net/l/by-sa/4.0/88x31.png
[cc-by-sa-shield]: https://img.shields.io/badge/License-CC%20BY--SA%204.0-lightgrey.svg

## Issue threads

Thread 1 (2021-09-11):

Feature: NMI / Bus Error / Reset header.

rvalles, 2021-09-11:
It would be nice to have footprints for a header (or multiple headers) exposing NMI, BERR and Reset.

Reset and BERR ([quite nifty exception](https://www.rvalles.net/bootstrapping-an-amiga-without-a-bootable-amiga-floppy.html)) can be used directly (connect to GND to trigger). NMI would need 3 diodes (connect IPL0..2 to GND).

This would allow me (amigaXfer dev) and other developers to trigger these without having to mess with the left expansion port.

jbilander, 2021-09-11:
Thanks for the info. If I make a new revision I will take a look at it, or perhaps if you are eager to have it now you could fork the repository and add it yourself. It is Open Source for a reason.

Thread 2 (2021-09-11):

Test and verify Autoconfig working with sidecard port expansions (e.g. A590) and implement DMA bus-arbitration.

jbilander, 2021-09-11:
Test and verify Autoconfig working with sidecard port expansions (e.g. A590).
/CFGIN is GND on the 86-pin expansion edge hence anything plugged in there will Autoconfig directly with no delay. In other words: Risk for bus-contention if the SF500 and for example an A590 Autoconfigs at the same time. However, /CFGOUT from that device should work and make it possible to connect a wire to /CFGIN of the SF500 in a daisy-chain manner (like in a A2000 zorro backplane). Need to experiment with this if/when I get my hands on an A590 or GVP.

Please don't fiddle with this unless you know what you are doing. Meaning don't plug anything into the side expansion of the A500 mobo with the SF500 installed unless you know what you are doing. Bus-contention might damage your hardware.

TODO:
Implement bus-arbitration and test sidecar expansions such as A590 and GVP HD+ to allow for DMA to the SF500 fast RAM.
https://github.com/jbilander/SF500/blob/main/ISE/SF500/rtl/main_top.v#L61

jbilander, 2021-12-23:
I have now implemented this and it looks like everything is playing nicely with an A590.

https://github.com/jbilander/SF500/commit/8cf910a10ba80b726cfbe80bd16cbdb67c184cc7

The A590 can for example be set to Amnesia (jumper setting on A590 PCB) and boot from its hard drive and DMA into the Fast RAM of the SF500.

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

For Autoconfig to work a jumper wire has to be connected/soldered from the CFGOUT on the expansion edge to the CFGIN on the SF500, like this:

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

I will leave this ticket open until other sidecar expansions such as a GVP HD8+ has been tested and confirmed working as well.

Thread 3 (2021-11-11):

How do i obtain a blank board?

blockchainbulls, 2021-11-11:
Anywhere I can buy? I'm not familiar with having PCBs printed.

dlxmax, 2021-11-11:
Yes, please share the gerbers on PCBWay's Shared Projects so that we can buy individual boards, and you get a little cut of the action too. Thanks!
https://www.pcbway.com/project/shareproject/

jbilander, 2021-11-11:
Hi, gerbers + drill files are available in a zip-file under _**Releases**_. You just have to upload the zip-file to your boardhouse e.g. JLCPCB.

dlxmax, 2021-11-11:
I suggested putting it up on Shared Projects because it allows people to buy just one board instead of the otherwise minimum 10.
Most of us would have 9 boards sitting in a drawer, which is uncomfortably wasteful ;)

blockchainbulls, 2021-11-11:
Thanks guys, very helpful. I uploaded the gerber files to shared projects on PCBWay.com and its under review.

Another question, what device do I need to program the rom chip?

blockchainbulls, 2021-11-11:
Okay, when I add my shared project to cart on PCBWay, it detects the board as only being 2 layers but I see in the notes that it is a 4 layer board.

blockchainbulls, 2021-11-11:
https://www.pcbway.com/project/shareproject/Spit_Fire_500___14mhz_Amiga_500_Accelerator_card.html

jbilander, 2021-11-11:
Hi, please remove the link to pcbway here on github (comment above) so people don't think I'm in any way linked to the donations you will receive from this. I only do Amiga stuff for a hobby. Not to make Money. Thanks

Closed 2021-11-11.

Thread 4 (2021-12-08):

Capacitor voltage?

blockchainbulls, 2021-12-08:
What voltage are the .1 and 10uf capacitors? I'm sure it's implied somehow and I'm just too green to realize. Thank you!

jbilander, 2021-12-08:
Hi, yes it's implied they need to be rated for at least 5V or higher.

Closed 2021-12-09.

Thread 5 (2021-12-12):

Question about the memory

blockchainbulls, 2021-12-12:
Hello, sorry for using your github issues page as my newbie training ground, but I am enjoying building the accelerator and I finally got the xilinx working and recognized in ISE. I have yet to acquire the ram though because of high prices. Please help me understand, why does the memory have to be 16mb if we are only using 4mb?  And does the memory have to be 5v or will 2.2v-3.6v memory work?

jbilander, 2021-12-12:
Hi, the size of memory chips are shown in Megabits not Megabytes. For example 2M x 8 or 1M x 16 means (2 Megabits times 8, or 1 Megabit times 16) hence the chip is 2 MB in size. On this accelerator (SF500) each chip is 2 MB in size so all memory is used. You can choose to only populate with two chips U5,U6 and put a jumper on JP2, 4MB will take you far in terms of WHDLoad gaming on the Amiga.

It is very unfortunate that someone bought all the cheap memory chips from Digikey. You see when I designed this accelerator they where available for only 4 € a piece.

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

Had I known this would happen I would've bought them all myself and resell for the same price just to make them available, but too late for that now.

Almost everything on the Amiga motherboard runs on 5V TTL logic levels. In order to use memory chips that are 3.3V you would need to have level shifters on every single adress- and dataline on the bus. otherwise you would let the magic smoke out. Putting level shifters can be done, look for example on the Vampire, but on this accelerator the space is very limited and also the CY62167G-45ZXI were very cheap when I designed the board.

blockchainbulls, 2021-12-13:
Thank you for the explanation. Will this memory work?

jbilander, 2021-12-13:
Hi,

No, that is FLASH memory (non-volatile) typically used for storage, it has to be asynchronous SRAM (volatile) memory...or you could redesign the PCB to take SDRAM type and implement a SDRAM-controller in Verilog.

blockchainbulls, 2021-12-15:
https://www.aliexpress.com/item/1005003256658439.html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

jbilander, 2021-12-15:
I think that should work if they are genuine Cypress chips.

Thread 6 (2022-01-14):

BOM error

perhof, 2022-01-14:
Hi,

Good job with the accellerator!

There's a minor error in the BOM regarding the decoupling caps for the SRAM. It says C5-C6 is for first 4MBs (U5-U6) and C7-C8 is for second optional 4MBs (U7-U8) which would have made sense and all but it's in fact C6 & C7 that is for the first 4MB and C5 & C8 is for the second 4MB. I thinkl people get it but might as well correct it, either in the BOM or in the schematic.

Some experiences that I'd want to share...

I used an SST39SF010 1mbit flash chip instead of the 29F040 because I had plenty on hand and it's pin compatible. SST39SF020 and SST39SF040 would have worked too. Could be an option if/when 29F040 are out of stock.

For the clock multipler, I couldn't get a NB3N502 because of the shortage but a Renesas 502MLF‎ worked just as well.

To bad the SRAM is so hard to get. Where did you find them at €4.18?
I had to buy the CY62167GE with ECC and it was much more expensive and was also in limited supply.  Do you think the CY62167GN-45ZXI would work? It's a little bit cheaper than the GE.

For the machined pins I pulled pins out of machined 40-pin header rows which are cheaper than the loose pins and I already had them on stock.
If the holes weren't drilled for machine pins I would have used this kind instead: https://www.aliexpress.com/item/4000106121057.html
They are durable and sits very well in sockets. Much harder to break than the machined pins too.
They are long so I stick them through the PCB from above and into a socket, then solder from above and cut off the remaining part.
If I need to build another SF500 I might make a variant for this.

It's also hard to use it with Rev 5 A500 PCBs where you need an adapter for the Kickstart ROM if you are going to use a newer ROM than the original 1.2/1.3 unless you modify the motherboard.

Finally I spent a whole lot of time troubleshooting the disk controller and I even built a second board because I though there was something wrong with my first build. Turned out it was an incompatibility with my CompactFlash card. which was a Transcend CompactFlash 800 32GB card. It just locked up the whole controller and computer as soon as it was attached and the controller was enabled. Couldn't boot from floppy either. Activity light on CF adapter was steady on.
Might want to stay away from that CF model.

Vi säger så :)
Mvh Per

jbilander, 2022-01-15:
Hi, thanks for sharing your findings. I'm glad you like it.

Actually the BOM is correct.
Capacitors being on the flipside has to do with limited board space for placing and routing, decoupling is for VCC-input on pin 37, VCC on pin 12 is only to hold CE2 high, it isn't neccessary but it doesn't hurt anything if you populate C7-C8 too in a two-chip-configuration (4 MB) build.

Regarding SRAM. I think CY62167GN-45ZXI and CY62167ELL-45ZXI should work as replacements, I haven't scrutinized the datasheets but taking a quick peek they seem almost identical. The Amiga is TTL logic levels so should be compatible with those logic levels from them SRAM-chips.

CY62167ELL-45ZXI can perhaps be sourced cheaply from link below, if they are genuine Cypress?, I don't know. They are only a quarter of the unit price at Mouser. When I designed this Accelerator there was no chip shortage and Digikey sold the Chips for unit price €4,18 with no warranty. The choice was easy. That's not the case now.

https://www.aliexpress.com/item/1005003256658439.html

Regarding A500 Rev 3 and Rev 5. You can make this low profile Kickstart ROM-switch mod and it shouldn't be a problem with clearance:
https://youtu.be/jSbbypYNPsk?t=1102

Regarding using the pins from the Stackable Long Legs Female Header. Aren't those too thick square-pins for the dip 64-pin socket sitting in the Amiga? If not they could work if you solder them at the correct length and in level. You see my first revision (1A) was with these kind of pins: https://www.aliexpress.com/item/32887861343.html  but the accelerator became too elevated touching the underside of the keyboard so you couldn't close the case. It's important to get the correct height to both give clearance for the 86-pin metal-shield to the left and the ROM-chip to the right (when the CF-adapter is installed). With using the pins in the BOM you get just that:
https://github.com/jbilander/SF500/blob/main/images/SF500_rev1b_pic6.jpg

Regards, J

perhof, 2022-01-15:
Iäl populate the caps on the bottom too then. I was going to sooner or later anyway but I need to get some more RAM first.

The CY62167ELL looks interesting. Good find! I will order some some from Counterfeitexpress and try :)

I have already designed a ROM adapter with an offset ROM so it relocates the ROM to the space between the ROM socket and the Agnus. I think that should do it.
I also had to replace an electrolytic cap on the rev 5 PCB near the pin 1 end of the 68k socket. It was a bit too tall for the PCB to clear it and the legs were to short to fold it out of the way. I put in a new cap and kept enough of the legs to be able to fold it away.

The machined pins you used in your first version is what I used too but I used them differently. I stripped all the plastic to get just get to the pins inside and populated them from the top of the PCB and cut away the remaning little tip on the top.

The stackable long headers are not square, they are flat so they are more like chip pins and they fit very well in sockets. The machined round ones have a tendency of falling out of dual wipe sockets. The flat ones don't do that. The socket gets a really secure grip on the pins and the pins don't destroy the socket as the square ones do. The downside is that they are a little bit trickier to solder because there is no frame on them that can be used to align them to the PCB. You have to use a socket under the PCB to keep both sideway position and elevation.
It doesn't show the shape of the pins very well in my pictures but I can send you a few samples if you would like to check them out.

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

perhof, 2022-02-03:
For your info, I purchased the CY62167ELL-45ZXI chips from https://www.aliexpress.com/item/1005003256658439.html for $3 each and they seem to work just fine.

jbilander, 2022-02-04:
Great to hear :)  ,thanks for the info. I will add it to the BOM.

Closed 2022-01-15.

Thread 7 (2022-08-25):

14Mhz perfect.. but not at 7Mhz :(

bekafoin, 2022-08-25:
Hi, I don't know if this is the right place to ask this but I have a "little" problem. I made this card following the instructions provided. When finished, I tried it in my A500+. The card works perfectly at 14Mhz (8M fast ram+ ide) but as soon as I switch to 7Mhz, the AMIGA crashes. Also the Amiga does not start when the switch is in the 7Mhz position (green screen). I tested the clock frequencies C7M, C14M, I have 7Mhz and 14Mhz. I also tested the CLKCPU signal, it goes well from 7 to 14 with the switch. I don't know where the problem can come from.
ps: I'm making a new board to see if I have the same defect but I'm still missing some components.

jbilander, 2022-08-26:
Hi, since it seems to be a problem with the 7 MHz, are you using a PLL-chip (NB3N502) that also has the reference clock signal output (REF)? Otherwise it won't work with 7 MHz. If yes, can you try the Accelerator in another machine to rule out if it's your Amiga or the Accelerator that is the problem. Green screen normally means you have problem with the chip ram in the Amiga. Run the AmigaTestKit to test all ram. I haven't heard any problem like you describe with SF500 before. Are you using components from reputable dealers like Mouser or Digikey? Buying ICs from AliExpress sometimes you get bad components mixed with good components.

bekafoin, 2022-08-27:
Hi and thank you for your reply. I measured 7Mhz on the REF pin. I also have 14Mhz on the CLKOUT pin. The NB3N502 seems to be working fine. The frequency also goes from 7 to 14 or from 14 to 7 when I use the switch on the CLKCPU pin. I have another A500+ but haven't tested it on this machine yet. I tested the ChipRam for about 30 min with the Amiga Test Kit without any faults. Where you're right is that my parts come from China :/ and I know it's a bit of a lottery... What's weird is that it works very well at 14Mhz. I'm going to do the test in my other A500+ and finish my 2nd board to see what happens. I'll come by to let you know. Thank you again for your work!!!

jbilander, 2022-08-27:
Hi, ok it sound like your CLK:s signals are working ok coming from the PLL. Perhaps there is some problem with the IC (U11) in the RC-debounce circuit . The RC (resistor-capacitor) circuit uses the hysteresis in a dual-inverting Schmitt-trigger IC for proper debounce in hardware. If this IC is faulty then the switching won't work. Try and replace this part (or for testing remove it and ground the pad/line to the CPLD will set it to start in 7 MHz). Check that you have the orientation correct of the IC. Also check that you used the correct values for resistors and capacitors in that circuit and that the soldering is ok.

One other thing is you could try is the older firmware that does not have the arbitration code implemented. It is more tested but you can't have anything connected to the expansion edge then (like a A590 or something) when you do the testing.

bekafoin, 2022-08-28:
Hello ! I removed U11 and I connected the SW1 signal directly to VCC but the problem remains. I checked my welds and all the parts but it seems correct. Last thing, I used the old firmware (21 09 02) and this time I still get a green screen on 7Mhz and nothing on 14Mhz :/ . I put back the latest firmware which at least works at 14Mhz. I wonder if it's not my Chinese CPLD is the cause .... I'll see if I have better luck with the 2nd board!

jbilander, 2022-08-28:
Hi, ok, yeah it sounds the CPLD could be bad. If you could try the Accelerator in another A500 and experience the same result then you could confirm the problem is with the Accelerator board and not that particular A500 machine you are testing on.
Best of luck with the 2nd build. Let me know how it goes.

bekafoin, 2022-08-28:
I tried the board in another A500+ with the same result, so the problem is with the board. I am waiting to receive what is needed for the 2nd board. I strongly suspect the CPLD! I'll be back to report... Thanks again for your help!

bekafoin, 2022-09-01:
Hi! I received my 29F040B and I was able to finish my 2nd board. Everything works as expected! I continue to look for what is wrong with the 1st!

hkzlab, 2024-08-29:
I am actually suffering the same issue (fine at 14Mhz, green screen at 7), and I built two boards.
My CPLD came from mouser (bought them a few years ago), actually all components came from Mouser except  the NB3N502s... and I'm beginning to suspect they could be the cause of the issue.

Attached is a screenshot of the input 7Mhz clock (green) compared with the 7Mhz clock out of the CPLD (yellow), and there is a significant phase shift. I wonder if this delay is introduced by the PLL.
I'll order a few more from a different seller on aliexpress, and if no luck, I'll get them from mouser at the next batch of components I order.

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

hkzlab, 2024-09-09:
And yes, after having replaced the PLL with one from a reputable source (Mouser), I do indeed confirm that the issue is solved for me too!

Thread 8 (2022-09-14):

how to boot from it ?

retroman75, 2022-09-14:
I have made it and everything works good I just don't know how to boot from it . I have kick ver 3.1.4 do I have to patch my rom and add same extra *.device drivers ?
Thank you !

jbilander, 2022-09-14:
Hi,

No patching needed. It will autoboot by default if you have the CFGIN-jumper on and JP4 is open.
If you still have problem it might be that the ROM-chip isn't programmed or soldered correctly.
You can check in SysInfo if the driver is loaded by clicking DEVICES and scroll down the list, you should see either oktagon or oktapussy driver has been loaded (from the ROM), depending on how you set JP3.

retroman75, 2022-09-15:
Hi , drivers are loaded and I can see them in sysinfo but hddtoolbox and sysinfo do not recognize drives . I have try SD and CF adapter , Any Idea what I'm doing wrong ?

retroman75, 2022-09-15:
OK , to have drives recognized we have to change scsi.device into oktagon.device for hddtoolbox .

jbilander, 2022-09-15:
Hi, ok I see you seem to have some progress now. I usually use WinUAE when partitioning and then I create a smaller FFS-partition ( couple of hundreds of megabytes) as the first primary partition so that it can boot also with KS 1.3.

https://github.com/jbilander/SF500/blob/main/images/SF500_rev1b_pic11.jpg

https://github.com/jbilander/SF500/blob/main/images/SF500_rev1b_pic12.jpg

retroman75, 2022-09-15:
I still don't know how to install workbench on the real Amiga . I have disk recognized in HDDtoolbox and I made partitions but after reset I can see them . Any ideas ? ... looks like 'save changes to disk' dose not save anything . HDsetup ends with error #80000003

jbilander, 2022-09-15:
Hi, after you have created partitions and saved your changes you need to reboot the machine and load workbench once again (from a floppy, the Install Disk). Then the partitions should appear on the desktop with a icon with a questionmark with garbled text, NDOS or similar, then you need to click on it and select format in the menu. Select quick-formatting. I normally use WinUAE to prepare the CF-card since I find it much easier. Don't forget to put the Max-transfer in and hit enter when creating partitions, the bug is still lingering in 3.1.4. It was finally fixed in 3.2. Check the pictures I linked to above.

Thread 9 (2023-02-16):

Card Builder in Europe?

lucdiniz, 2023-02-16:
Hello @jbilander,
Do you know anyone building this card in europe? I found that in PCBway we can build the PCB but only on batch of 5.
I don't need so many and I don't have the tools to build and burn any chip.
Can you help on this?
Many Thanks and great work

jbilander, 2023-02-17:
Hi, no sorry I don't know anyone building them and I don't have time to build any myself, and also the Xilinx-CPLD-chip is out of stock (due to chip shortage). I will probably build a couple of SF2000 that I released the other day here on GitHub. I will have a few spare blank PCBs I could sell but it is DIY to build it.

Regards, J

bipbopbap, 2023-02-23:
I would be interested in a PCB for hobby building. Maybe a bit long-term I could source the components. I would like to see if the board could fit in my A1000.
I also have a A2000 that is currently under "reconstruction". Are you selling the SF2000 too?
/Ulf

jbilander, 2023-02-24:
Hi @bipbopbap Unfortunately I don't have any spare SF500 PCBs, but you have the rev 1b gerber+drill file in a zip under releases if you want to upload to JLCPCB and have them make boards for you. The minimum order qty is 5 pcs though.

I will have some spare PCBs of the SF2000 soon. I have an order on the way from JLCPCB. Let me know if you are interested in one of those (for cost). It is a blank PCB, color blue, no components. Well I have some spare connectors. Also the Firmware is not finished for SF2000 and this is a hobby project so there are no guarantees on further FW-development. It is done when time allows. My hope with these extra PCBs is that someone can help with development and testing and not only buy it for normal usage. I don't have an A2000 myself to test the card in together with other cards, only A500.

I think the SF500 should work in the A1000 if it fits?

My email if you are interested in a blank SF2000 PCB:
jorgen.bilander at gmail com

Regards, J

lucdiniz, 2024-02-19:
Hello @jbilander,
Just to ping if you know anyone building your board? I only want one :)
Thanks

Alice-21, 2025-09-28:
> Hello [@jbilander](https://github.com/jbilander), Just to ping if you know anyone building your board? I only want one :) Thanks

Still interested?

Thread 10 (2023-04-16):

Will thsi fit in an A2000 ?

levo-man, 2023-04-16:
I would like to add a small accelerator to my A2000 and would like to know if this will physically fit and work ?

jbilander, 2023-04-17:
Hi, it will not fit in the 68k CPU-socket unless you stack it (elevate it) with a couple of pin-strips. That will work but maybe not the prettiest solution. Another way would be to use a re-locator that goes in the co-pro slot of the A2000. There is a re-locator that looks like this that I think should work:

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

I haven't tested it though.
Another obvious option is to go for the SF2000 instead.

levo-man, 2023-04-17:
Considering both options , but will probably go for the cheaper
solution.
Thanks for the Info .

------ Original Message ------
From "Jorgen Bilander" ***@***.***>
To "jbilander/SF500" ***@***.***>
Cc "levo-man" ***@***.***>; "Author"
***@***.***>
Date 17/04/2023 12:23:58
Subject Re: [jbilander/SF500] Will this fit in an A2000 ? (Issue #10)

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

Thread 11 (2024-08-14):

AM29F040B-70JC ROM image to burn

Vanles, 2024-08-14:
Hello @jbilander

I don't quite understand what I have to write to the AM29F040B-70JC. Do I have to adjust the ATOKTACOMBINED.rom-512.bin? Is there a ready-made .bin that I can just write to the chip?

Thanks

jbilander, 2024-08-14:
Hi,

You don't have to adjust the bin file, it is ready for burning, just use your ROM-programmer to write it to the AM29F040B-70JC before you solder it in place.

Instructions are here:
https://github.com/jbilander/SF500?tab=readme-ov-file#how-to-build

Vanles, 2024-08-14:
I couldn't find the .rom file at first, but now I have everything.
Now I know that it doesn’t have to be adjusted.
Thanks

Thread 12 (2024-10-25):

U11 - 74HCT2G14 - where is pin 1?

Vanles, 2024-10-25:
Hello,

I have a problem with U11 and the 74HCT2G14. Which way does this belong on the board, where is pin 1?

Thanks
Marco

jbilander, 2024-10-26:
Hi,

The long line on the silkscreen (right under the U11 reference ) marks pin 1. Indicating pin 1 this way was standard in KiCad 5 footprints. If you look carefully it's the same on the other chips as well, a long line indicating pin 1.

Regards

Vanles, 2024-10-26:
Thanks

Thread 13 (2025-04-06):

Blasck or GREEN screen

nbdy32, 2025-04-06:
Hi, have problem with the SF500, on turning the amiga on I have black or green screen ...

Now the question, the amiga is a rev.6 board and has a memory expansion with gary adapter so the JP2 i cut and a wire soldered to JP2 (up) for gary adapter

Can this 2 work together, or do I have to desolder the wire and solder the jumper ???

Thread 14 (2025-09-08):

Small Concern About the PLL Chip

Vanles, 2025-09-08:
Hi,
the Spitfire500 is really great, I love using it in my A500 — and even tried it out in a friend’s one.

The only issue I see coming up soon is that the PLL chip (NB3N502) won’t be available anymore. Mouser and DigiKey don’t carry it now, so there’s no serious source left.

Would it maybe be possible for you to release an updated PCB with an alternative chip? It would be a real shame if this board couldn’t be built anymore.

Thanks a lot for your awesome PCBs!

Vanles, 2025-09-08:
Thank you very much for the information.

Yes, the prices are very high. The SF2000 is also very interesting. Is it currently working, or should I rather wait a bit before ordering PCBs?

An A500 version would be great.

Thanks

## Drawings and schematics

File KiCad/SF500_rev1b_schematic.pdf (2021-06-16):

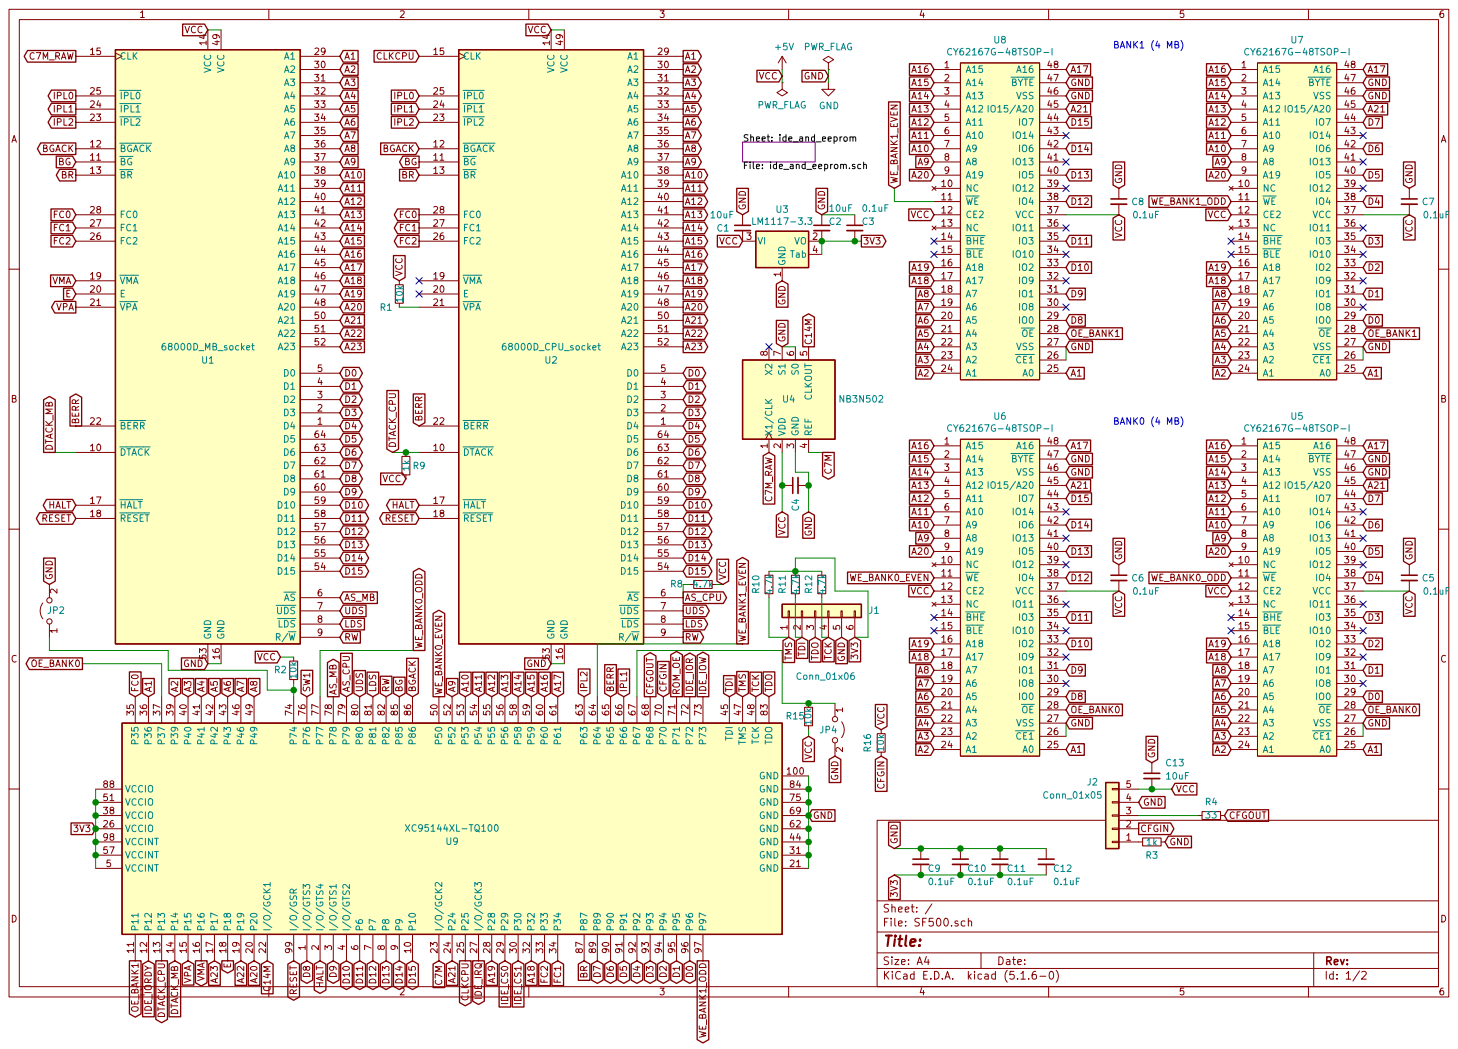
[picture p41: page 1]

3V3 TDI TMS TCK TDO

9 P10 10 P20 20 P30 30 P40 40 P50 50 P60 60 P70 70 P80 80 P90 90 P11 11 GND 21 GND 31 P41 41 VCCIO 51 P61 61 P71 71 P81 81 P91 91 P12 12 I/O/GCK1 22 P32 32 P42 42 P52 52 GND 62 P72 72 P82 82 P92 92 P13 13 I/O/GCK2 23 P33 33 P43 43 P53 53 P63 63 P73 73 TDO 83 P93 93 P14 14 P24 24 P34 34 GND 44 P54 54 P64 64 P74 74 GND 84 P94 94 P15 15 P25 25 P35 35 TDI 45 P55 55 P65 65 GND 75 P85 85 P95 95 P16 16 VCCIO 26 P36 36 P46 46 P56 56 P66 66 P76 76 P86 86 P96 96 P17 17 I/O/GCK3 27 P37 37 TMS 47

Id: 1/2 Title: File: SF500.sch Sheet: /

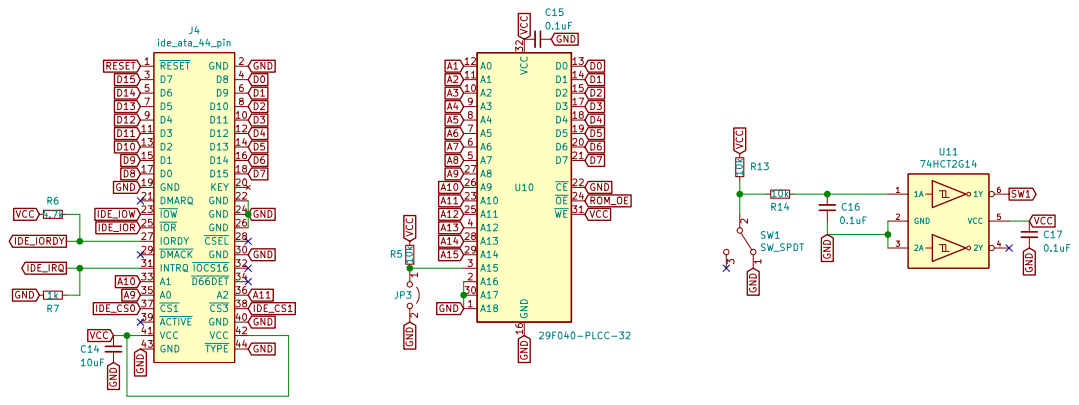
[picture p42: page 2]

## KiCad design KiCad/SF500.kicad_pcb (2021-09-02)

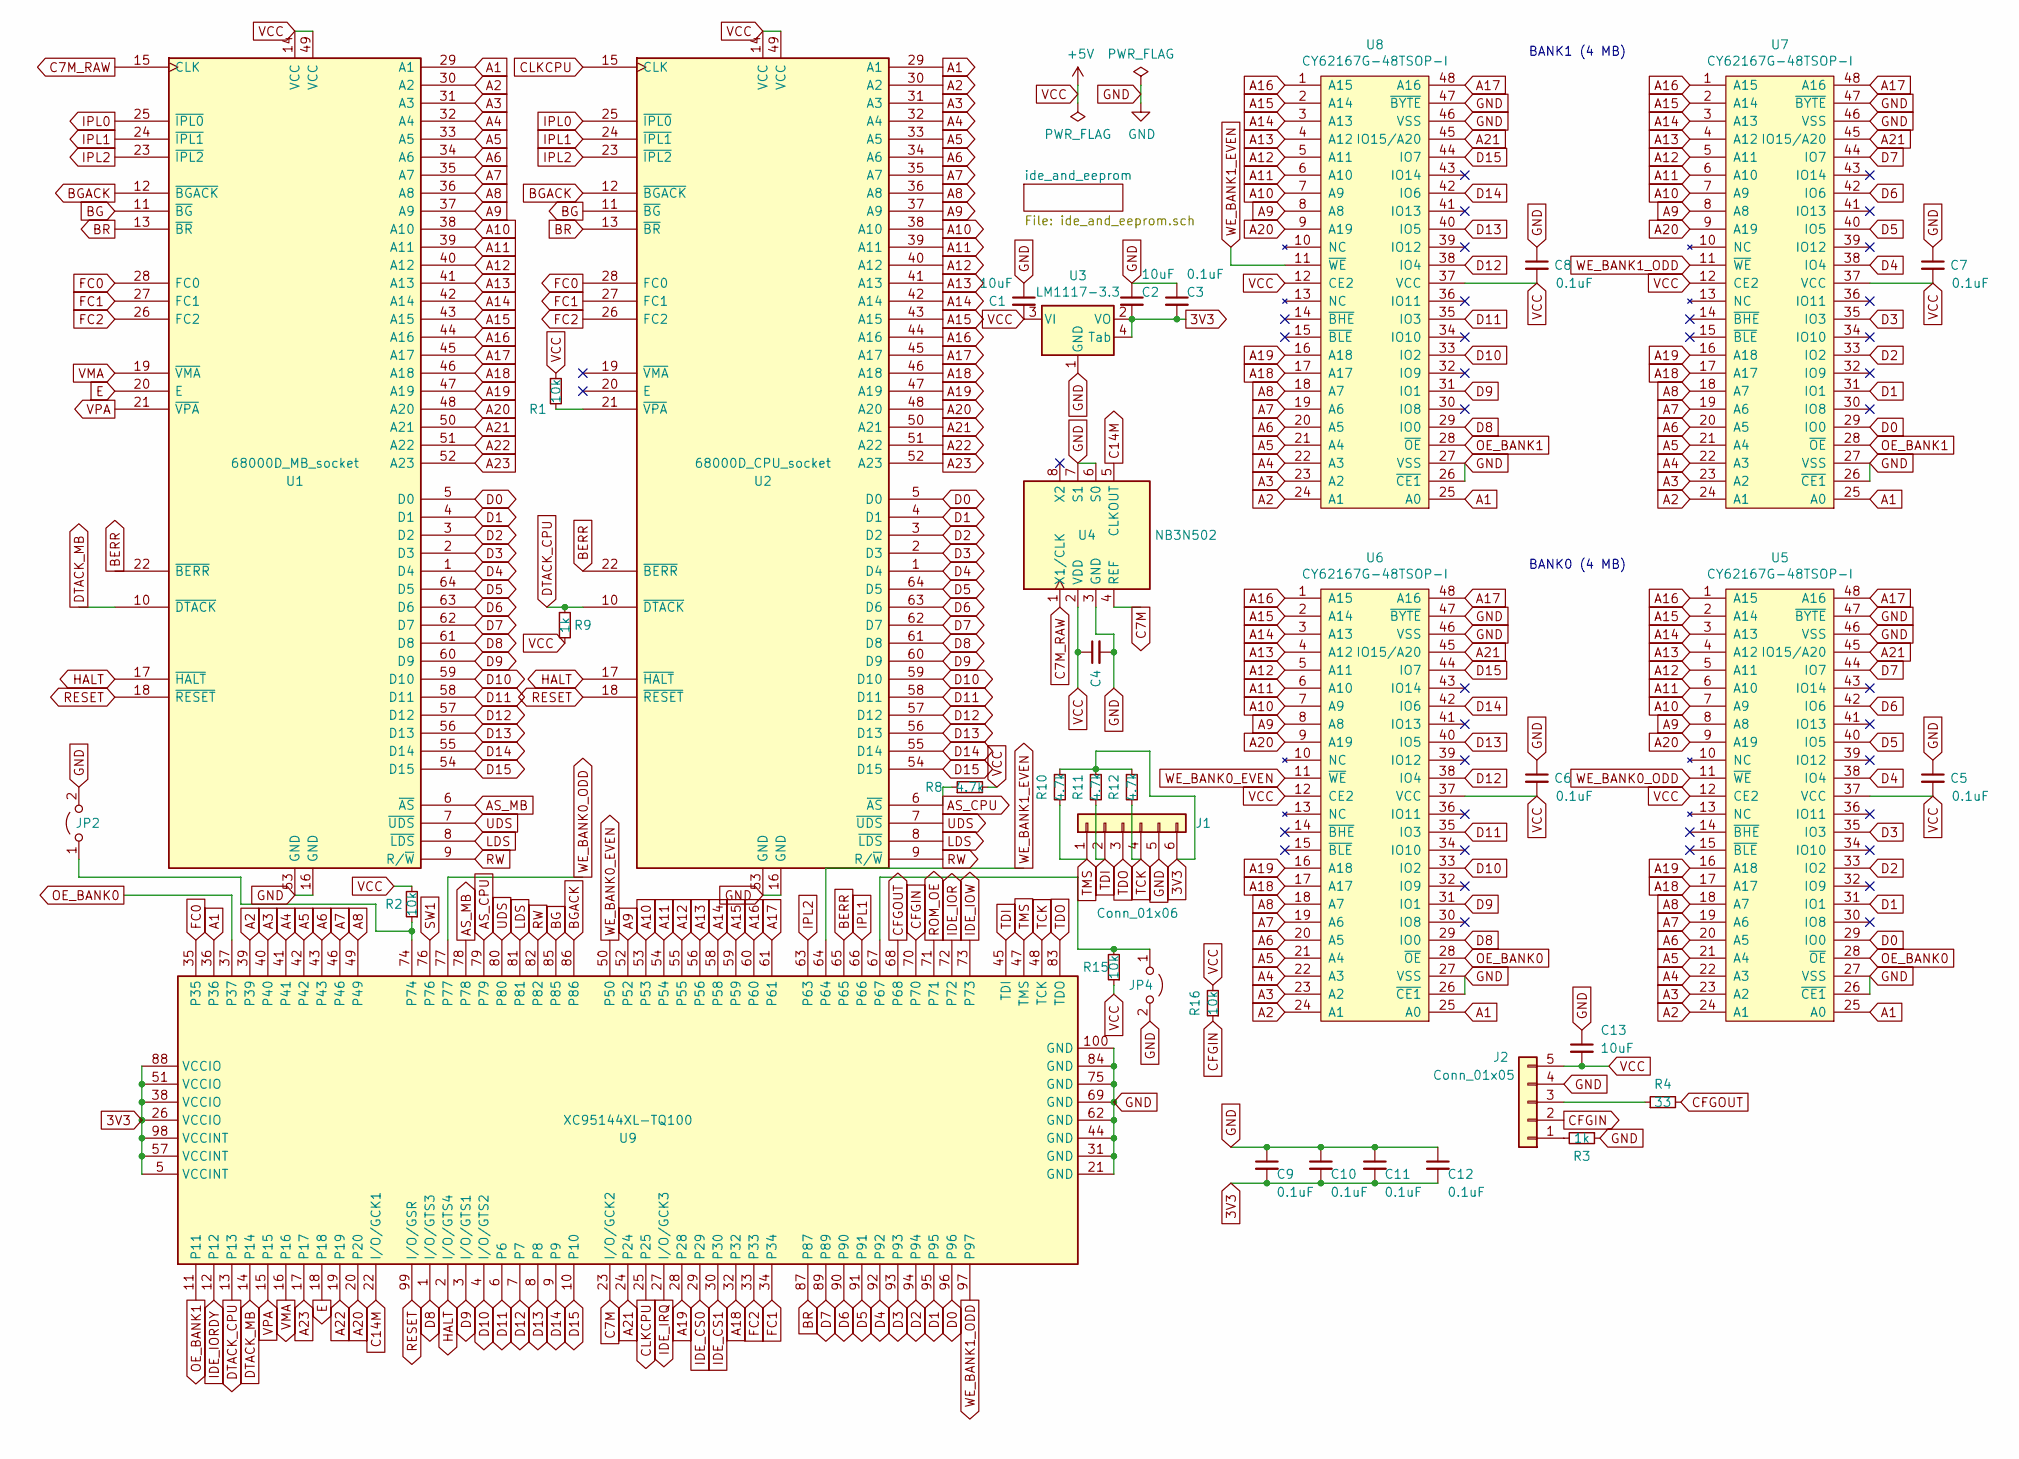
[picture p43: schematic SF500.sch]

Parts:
C1, C2, C13: 10uF; C_1206_3216Metric_Pad1.42x1.75mm_HandSolder
C3, C5, C6, C7, C8, C9, C10, C11, C12: 0.1uF; C_0805_2012Metric_Pad1.15x1.40mm_HandSolder
C4: 100nF; C_0805_2012Metric_Pad1.15x1.40mm_HandSolder
J1: Conn_01x06; PinHeader_1x06_P2.54mm_Vertical
J2: Conn_01x05; PinHeader_1x05_P2.54mm_Horizontal
JP2, JP4: Jumper_2_Open; PinHeader_1x02_P2.54mm_Vertical
R1, R2, R15: 10k; R_1206_3216Metric_Pad1.42x1.75mm_HandSolder
R3, R9: 1k; R_1206_3216Metric_Pad1.42x1.75mm_HandSolder
R4: 33; R_1206_3216Metric_Pad1.42x1.75mm_HandSolder
R8: 4.7k; R_1206_3216Metric_Pad1.42x1.75mm_HandSolder
R10, R11, R12: 4.7k; R_0805_2012Metric_Pad1.15x1.40mm_HandSolder
R16: 10k; R_0805_2012Metric_Pad1.15x1.40mm_HandSolder
U1: 68000D_MB_socket; DIP-64_W22.86mm_LongPads
U2: 68000D_CPU_socket; DIP-64_W22.86mm_LongPads
U3: LM1117-3.3; SOT-223
U4: NB3N502; SOIC-8_3.9x4.9mm_P1.27mm
U5, U6, U7, U8: CY62167G-48TSOP-I; TSOP-I-48_18.4x12mm_P0.5mm
U9: XC95144XL-TQ100; TQFP-100_14x14mm_P0.5mm

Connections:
3V3: C2.2, C3.2, C9.2, C10.2, C11.2, C12.2, J1.6, R10.1, R11.1, R12.1, U3.2 (VO), U3.4 (Tab), U9.5 (VCCINT), U9.26 (VCCIO), U9.38 (VCCIO), U9.51 (VCCIO), U9.57 (VCCINT), U9.88 (VCCIO), U9.98 (VCCINT)
A1: U1.29 (A1), U2.29 (A1), U5.25 (A0), U6.25 (A0), U7.25 (A0), U8.25 (A0), U9.36; also elsewhere on the board
A2: U1.30 (A2), U2.30 (A2), U5.24 (A1), U6.24 (A1), U7.24 (A1), U8.24 (A1), U9.39; also elsewhere on the board
A3: U1.31 (A3), U2.31 (A3), U5.23 (A2), U6.23 (A2), U7.23 (A2), U8.23 (A2), U9.40; also elsewhere on the board
A4: U1.32 (A4), U2.32 (A4), U5.22 (A3), U6.22 (A3), U7.22 (A3), U8.22 (A3), U9.41; also elsewhere on the board
A5: U1.33 (A5), U2.33 (A5), U5.21 (A4), U6.21 (A4), U7.21 (A4), U8.21 (A4), U9.42; also elsewhere on the board
A6: U1.34 (A6), U2.34 (A6), U5.20 (A5), U6.20 (A5), U7.20 (A5), U8.20 (A5), U9.43; also elsewhere on the board
A7: U1.35 (A7), U2.35 (A7), U5.19 (A6), U6.19 (A6), U7.19 (A6), U8.19 (A6), U9.46; also elsewhere on the board
A8: U1.36 (A8), U2.36 (A8), U5.18 (A7), U6.18 (A7), U7.18 (A7), U8.18 (A7), U9.49; also elsewhere on the board
A9: U1.37 (A9), U2.37 (A9), U5.8 (A8), U6.8 (A8), U7.8 (A8), U8.8 (A8), U9.52; also elsewhere on the board
A10: U1.38 (A10), U2.38 (A10), U5.7 (A9), U6.7 (A9), U7.7 (A9), U8.7 (A9), U9.53; also elsewhere on the board
A11: U1.39 (A11), U2.39 (A11), U5.6 (A10), U6.6 (A10), U7.6 (A10), U8.6 (A10), U9.54; also elsewhere on the board
A12: U1.40 (A12), U2.40 (A12), U5.5 (A11), U6.5 (A11), U7.5 (A11), U8.5 (A11), U9.55; also elsewhere on the board
A13: U1.41 (A13), U2.41 (A13), U5.4 (A12), U6.4 (A12), U7.4 (A12), U8.4 (A12), U9.56; also elsewhere on the board
A14: U1.42 (A14), U2.42 (A14), U5.3 (A13), U6.3 (A13), U7.3 (A13), U8.3 (A13), U9.58; also elsewhere on the board
A15: U1.43 (A15), U2.43 (A15), U5.2 (A14), U6.2 (A14), U7.2 (A14), U8.2 (A14), U9.59; also elsewhere on the board
A16: U1.44 (A16), U2.44 (A16), U5.1 (A15), U6.1 (A15), U7.1 (A15), U8.1 (A15), U9.60
A17: U1.45 (A17), U2.45 (A17), U5.48 (A16), U6.48 (A16), U7.48 (A16), U8.48 (A16), U9.61
A18: U1.46 (A18), U2.46 (A18), U5.17 (A17), U6.17 (A17), U7.17 (A17), U8.17 (A17), U9.32
A19: U1.47 (A19), U2.47 (A19), U5.16 (A18), U6.16 (A18), U7.16 (A18), U8.16 (A18), U9.28
A20: U1.48 (A20), U2.48 (A20), U5.9 (A19), U6.9 (A19), U7.9 (A19), U8.9 (A19), U9.20
A21: U1.50 (A21), U2.50 (A21), U5.45 (IO15/A20), U6.45 (IO15/A20), U7.45 (IO15/A20), U8.45 (IO15/A20), U9.24
A22: U1.51 (A22), U2.51 (A22), U9.19
A23: U1.52 (A23), U2.52 (A23), U9.17
AS_CPU: R8.1, U2.6 (~AS), U9.79
AS_MB: U1.6 (~AS), U9.78
BERR: U1.22 (~BERR), U2.22 (~BERR), U9.65
BG: U1.11 (~BG), U2.11 (~BG), U9.85
BGACK: U1.12 (~BGACK), U2.12 (~BGACK), U9.86
BR: U1.13 (~BR), U2.13 (~BR), U9.87
C7M: U4.4 (REF), U9.23 (I/O/GCK2)
C7M_RAW: U1.15 (CLK), U4.1 (X1/CLK)
C14M: U4.5 (CLKOUT), U9.22 (I/O/GCK1)
CFGIN: J2.2, R16.1, U9.70
CFGOUT: R4.2, U9.68
CLKCPU: U2.15 (CLK), U9.25
D0: U1.5 (D0), U2.5 (D0), U5.29 (IO0), U7.29 (IO0), U9.96; also elsewhere on the board
D1: U1.4 (D1), U2.4 (D1), U5.31 (IO1), U7.31 (IO1), U9.95; also elsewhere on the board
D2: U1.3 (D2), U2.3 (D2), U5.33 (IO2), U7.33 (IO2), U9.94; also elsewhere on the board
D3: U1.2 (D3), U2.2 (D3), U5.35 (IO3), U7.35 (IO3), U9.93; also elsewhere on the board
D4: U1.1 (D4), U2.1 (D4), U5.38 (IO4), U7.38 (IO4), U9.92; also elsewhere on the board
D5: U1.64 (D5), U2.64 (D5), U5.40 (IO5), U7.40 (IO5), U9.91; also elsewhere on the board
D6: U1.63 (D6), U2.63 (D6), U5.42 (IO6), U7.42 (IO6), U9.90; also elsewhere on the board
D7: U1.62 (D7), U2.62 (D7), U5.44 (IO7), U7.44 (IO7), U9.89; also elsewhere on the board
D8: U1.61 (D8), U2.61 (D8), U6.29 (IO0), U8.29 (IO0), U9.1 (I/O/GTS3); also elsewhere on the board
D9: U1.60 (D9), U2.60 (D9), U6.31 (IO1), U8.31 (IO1), U9.3 (I/O/GTS1); also elsewhere on the board
D10: U1.59 (D10), U2.59 (D10), U6.33 (IO2), U8.33 (IO2), U9.4 (I/O/GTS2); also elsewhere on the board
D11: U1.58 (D11), U2.58 (D11), U6.35 (IO3), U8.35 (IO3), U9.6; also elsewhere on the board
D12: U1.57 (D12), U2.57 (D12), U6.38 (IO4), U8.38 (IO4), U9.7; also elsewhere on the board
D13: U1.56 (D13), U2.56 (D13), U6.40 (IO5), U8.40 (IO5), U9.8; also elsewhere on the board
D14: U1.55 (D14), U2.55 (D14), U6.42 (IO6), U8.42 (IO6), U9.9; also elsewhere on the board
D15: U1.54 (D15), U2.54 (D15), U6.44 (IO7), U8.44 (IO7), U9.10; also elsewhere on the board
DTACK_CPU: R9.1, U2.10 (~DTACK), U9.13
DTACK_MB: U1.10 (~DTACK), U9.14
E: U1.20 (E), U9.18
FC0: U1.28 (FC0), U2.28 (FC0), U9.35
FC1: U1.27 (FC1), U2.27 (FC1), U9.34
FC2: U1.26 (FC2), U2.26 (FC2), U9.33
GND: C1.1, C2.1, C3.1, C4.2, C5.1, C6.1, C7.1, C8.1, C9.1, C10.1, C11.1, C12.1, C13.1, J1.5, J2.4, JP2.2 (B), JP4.2 (B), R3.1, U1.16 (GND), U1.53 (GND), U2.16 (GND), U2.53 (GND), U3.1 (GND), U4.3 (GND), U4.6 (S0), U4.7 (S1), U5.26 (~CE1), U5.27 (VSS), U5.46 (VSS), U5.47 (~BYTE), U6.26 (~CE1), U6.27 (VSS), U6.46 (VSS), U6.47 (~BYTE), U7.26 (~CE1), U7.27 (VSS), U7.46 (VSS), U7.47 (~BYTE), U8.26 (~CE1), U8.27 (VSS), U8.46 (VSS), U8.47 (~BYTE), U9.21 (GND), U9.31 (GND), U9.44 (GND), U9.62 (GND), U9.69 (GND), U9.75 (GND), U9.84 (GND), U9.100 (GND); also elsewhere on the board
HALT: U1.17 (~HALT), U2.17 (~HALT), U9.2 (I/O/GTS4)
IDE_CS0: U9.29; also elsewhere on the board
IDE_CS1: U9.30; also elsewhere on the board
IDE_IOR: U9.72; also elsewhere on the board
IDE_IORDY: U9.12; also elsewhere on the board
IDE_IOW: U9.73; also elsewhere on the board
IDE_IRQ: U9.27 (I/O/GCK3); also elsewhere on the board
IPL0: U1.25 (~IPL0), U2.25 (~IPL0)
IPL1: U1.24 (~IPL1), U2.24 (~IPL1), U9.66
IPL2: U1.23 (~IPL2), U2.23 (~IPL2), U9.63
LDS: U1.8 (~LDS), U2.8 (~LDS), U9.81
unnamed: J2.1, R3.2
unnamed: J2.3, R4.1
unnamed: JP2.1 (A), R2.1, U9.74
unnamed: JP4.1 (A), R15.2, U9.67
unnamed: R1.2, U2.21 (~VPA)
OE_BANK0: U5.28 (~OE), U6.28 (~OE), U9.37
OE_BANK1: U7.28 (~OE), U8.28 (~OE), U9.11
RESET: U1.18 (~RESET), U2.18 (~RESET), U9.99 (I/O/GSR); also elsewhere on the board
ROM_OE: U9.71; also elsewhere on the board
RW: U1.9 (R/~W), U2.9 (R/~W), U9.82
SW1: U9.76; also elsewhere on the board
TCK: J1.4, R12.2, U9.48 (TCK)
TDI: J1.2, R11.2, U9.45 (TDI)
TDO: J1.3, U9.83 (TDO)
TMS: J1.1, R10.2, U9.47 (TMS)
UDS: U1.7 (~UDS), U2.7 (~UDS), U9.80
VCC: C1.2, C4.1, C5.2, C6.2, C7.2, C8.2, C13.2, J2.5, R1.1, R2.2, R8.2, R9.2, R15.1, R16.2, U1.14 (VCC), U1.49 (VCC), U2.14 (VCC), U2.49 (VCC), U3.3 (VI), U4.2 (VDD), U5.12 (CE2), U5.37 (VCC), U6.12 (CE2), U6.37 (VCC), U7.12 (CE2), U7.37 (VCC), U8.12 (CE2), U8.37 (VCC); also elsewhere on the board
VMA: U1.19 (~VMA), U9.16
VPA: U1.21 (~VPA), U9.15
WE_BANK0_EVEN: U6.11 (~WE), U9.50
WE_BANK0_ODD: U5.11 (~WE), U9.77
WE_BANK1_EVEN: U8.11 (~WE), U9.64
WE_BANK1_ODD: U7.11 (~WE), U9.97

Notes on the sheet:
BANK0 (4 MB)
BANK1 (4 MB)

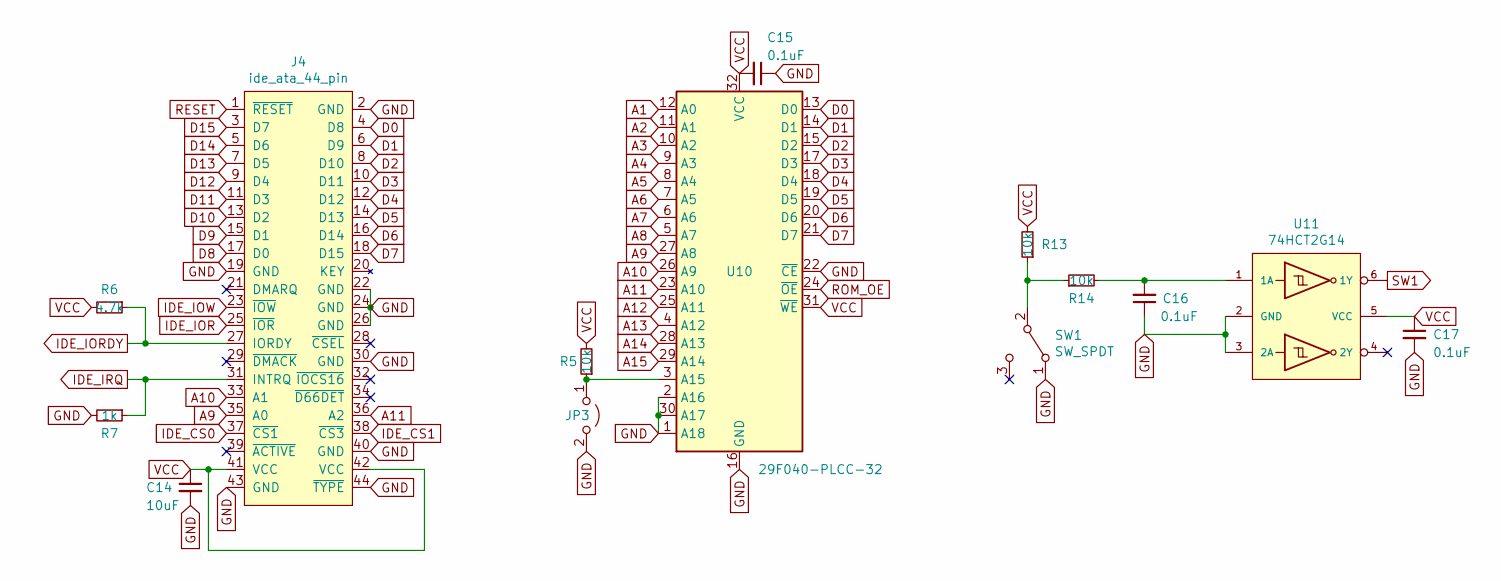
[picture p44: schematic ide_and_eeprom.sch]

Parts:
C14: 10uF; C_1206_3216Metric_Pad1.42x1.75mm_HandSolder
C15, C16, C17: 0.1uF; C_0805_2012Metric_Pad1.15x1.40mm_HandSolder
J4: ide_ata_44_pin; PinSocket_2x22_P2.00mm_Horizontal
JP3: Jumper_2_Open; PinHeader_1x02_P2.54mm_Vertical
R5: 10k; R_1206_3216Metric_Pad1.42x1.75mm_HandSolder
R6: 4.7k; R_1206_3216Metric_Pad1.42x1.75mm_HandSolder
R7: 1k; R_1206_3216Metric_Pad1.42x1.75mm_HandSolder
R13, R14: 10k; R_0805_2012Metric_Pad1.15x1.40mm_HandSolder
SW1: SW_SPDT; PinHeader_1x03_P2.54mm_Vertical
U10: 29F040-PLCC-32; PLCC-32_11.4x14.0mm_P1.27mm
U11: 74HCT2G14; TSOP-6_1.65x3.05mm_P0.95mm

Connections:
A1: U10.12 (A0); also elsewhere on the board
A2: U10.11 (A1); also elsewhere on the board
A3: U10.10 (A2); also elsewhere on the board
A4: U10.9 (A3); also elsewhere on the board
A5: U10.8 (A4); also elsewhere on the board
A6: U10.7 (A5); also elsewhere on the board
A7: U10.6 (A6); also elsewhere on the board
A8: U10.5 (A7); also elsewhere on the board
A9: J4.35 (A0), U10.27 (A8); also elsewhere on the board
A10: J4.33 (A1), U10.26 (A9); also elsewhere on the board
A11: J4.36 (A2), U10.23 (A10); also elsewhere on the board
A12: U10.25 (A11); also elsewhere on the board
A13: U10.4 (A12); also elsewhere on the board
A14: U10.28 (A13); also elsewhere on the board
A15: U10.29 (A14); also elsewhere on the board
D0: J4.4 (D8), U10.13 (D0); also elsewhere on the board
D1: J4.6 (D9), U10.14 (D1); also elsewhere on the board
D2: J4.8 (D10), U10.15 (D2); also elsewhere on the board
D3: J4.10 (D11), U10.17 (D3); also elsewhere on the board
D4: J4.12 (D12), U10.18 (D4); also elsewhere on the board
D5: J4.14 (D13), U10.19 (D5); also elsewhere on the board
D6: J4.16 (D14), U10.20 (D6); also elsewhere on the board
D7: J4.18 (D15), U10.21 (D7); also elsewhere on the board
D8: J4.17 (D0); also elsewhere on the board
D9: J4.15 (D1); also elsewhere on the board
D10: J4.13 (D2); also elsewhere on the board
D11: J4.11 (D3); also elsewhere on the board
D12: J4.9 (D4); also elsewhere on the board
D13: J4.7 (D5); also elsewhere on the board
D14: J4.5 (D6); also elsewhere on the board
D15: J4.3 (D7); also elsewhere on the board
GND: C14.2, C15.1, C16.1, C17.2, J4.2 (GND), J4.19 (GND), J4.22 (GND), J4.24 (GND), J4.26 (GND), J4.30 (GND), J4.40 (GND), J4.43 (GND), J4.44 (~TYPE), JP3.2 (B), R7.2, SW1.1 (A), U10.1 (A18), U10.2 (A16), U10.16 (GND), U10.22 (~CE), U10.30 (A17), U11.2 (GND), U11.3 (2A); also elsewhere on the board
IDE_CS0: J4.37 (~CS1); also elsewhere on the board
IDE_CS1: J4.38 (~CS3); also elsewhere on the board
IDE_IOR: J4.25 (~IOR); also elsewhere on the board
IDE_IORDY: J4.27 (IORDY), R6.1; also elsewhere on the board
IDE_IOW: J4.23 (~IOW); also elsewhere on the board
IDE_IRQ: J4.31 (INTRQ), R7.1; also elsewhere on the board
unnamed: C16.2, R14.2, U11.1 (1A)
unnamed: JP3.1 (A), R5.1, U10.3 (A15)
unnamed: R13.1, R14.1, SW1.2 (B)
RESET: J4.1 (~RESET); also elsewhere on the board
ROM_OE: U10.24 (~OE); also elsewhere on the board
SW1: U11.6 (1Y); also elsewhere on the board
VCC: C14.1, C15.2, C17.1, J4.41 (VCC), J4.42 (VCC), R5.2, R6.2, R13.2, U10.31 (~WE), U10.32 (VCC), U11.5 (VCC); also elsewhere on the board

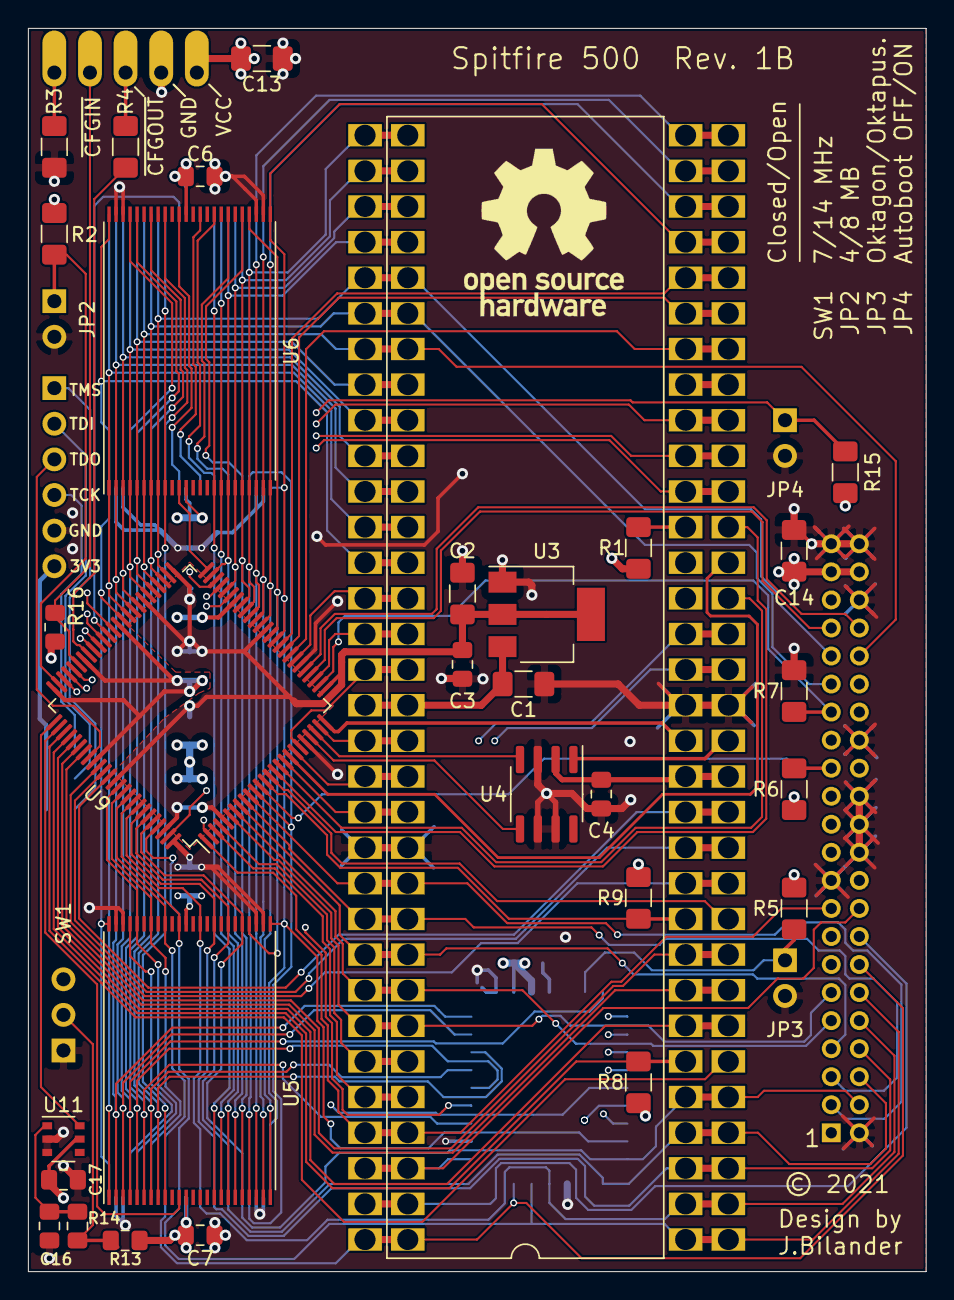
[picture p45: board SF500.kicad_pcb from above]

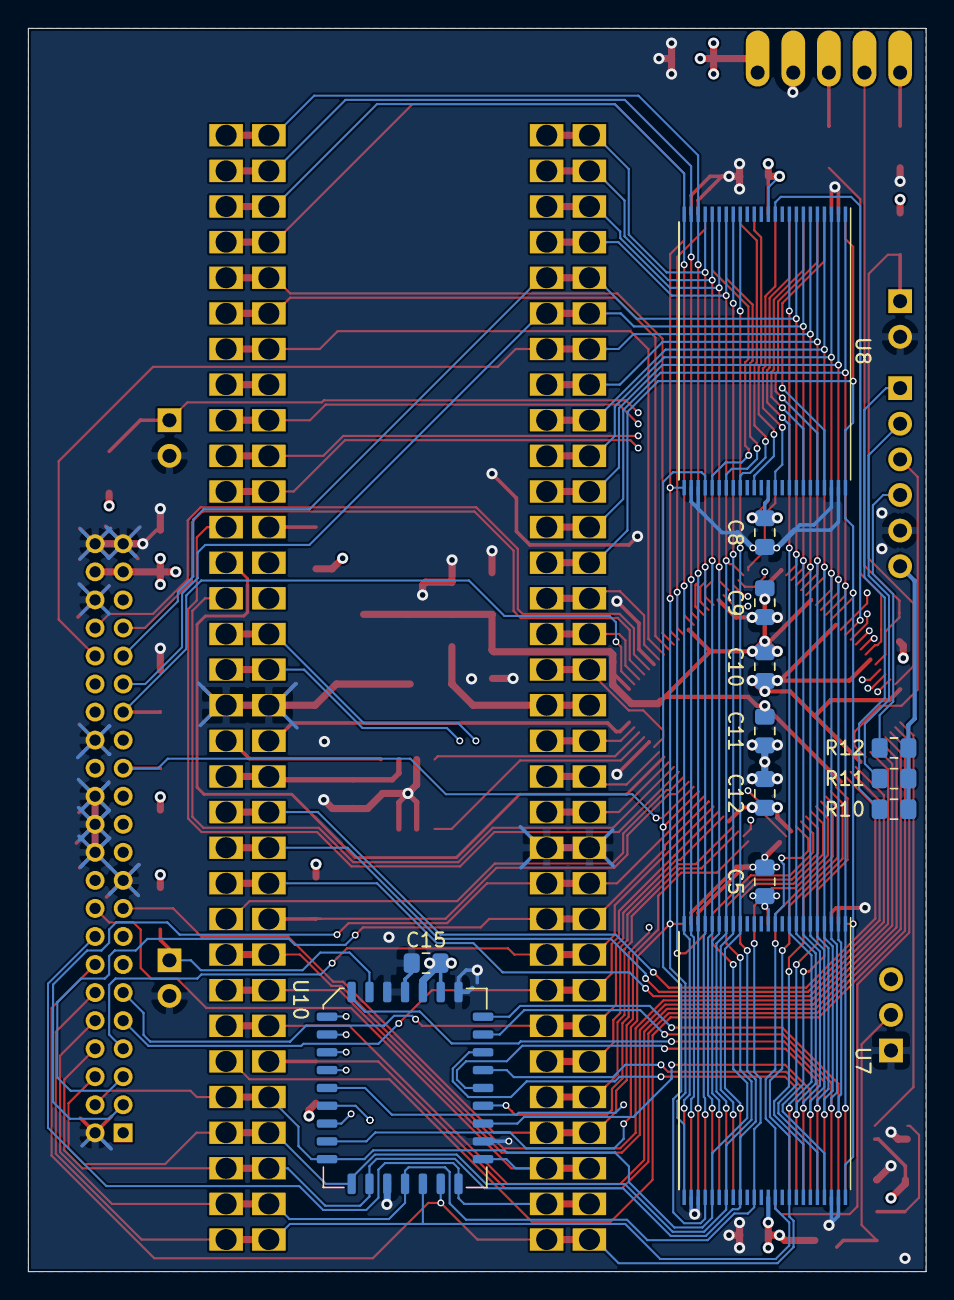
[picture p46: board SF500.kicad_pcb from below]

Board: 4 copper layers, 64.0 x 88.6 mm, 51 parts (13 on the bottom side), 96 nets.

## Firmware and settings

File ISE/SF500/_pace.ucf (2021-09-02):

#PACE: Start of Constraints generated by PACE

#PACE: Start of PACE I/O Pin Assignments
NET "A12"  LOC = "P55"  ; 
NET "A13"  LOC = "P56"  ; 
NET "A_HIGH<16>"  LOC = "P60"  ; 
NET "A_HIGH<17>"  LOC = "P61"  ; 
NET "A_HIGH<18>"  LOC = "P32"  ; 
NET "A_HIGH<19>"  LOC = "P28"  ; 
NET "A_HIGH<20>"  LOC = "P20"  ; 
NET "A_HIGH<21>"  LOC = "P24"  ; 
NET "A_HIGH<22>"  LOC = "P19"  ; 
NET "A_HIGH<23>"  LOC = "P17"  ; 
NET "A_LOW<1>"  LOC = "P36"  ; 
NET "A_LOW<2>"  LOC = "P39"  ; 
NET "A_LOW<3>"  LOC = "P40"  ; 
NET "A_LOW<4>"  LOC = "P41"  ; 
NET "A_LOW<5>"  LOC = "P42"  ; 
NET "A_LOW<6>"  LOC = "P43"  ; 
NET "AS_CPU_n"  LOC = "P79"  ; 
NET "AS_MB_n"  LOC = "P78"  ; 
NET "C14M"  LOC = "P22" | BUFG = CLK ; 
NET "C7M"  LOC = "P23" | BUFG = CLK ; 
NET "CFGIN_n"  LOC = "P70"  ; 
NET "CFGOUT_n"  LOC = "P68"  ; 
NET "CLKCPU"  LOC = "P25"  ; 
NET "D<12>"  LOC = "P7"  ; 
NET "D<13>"  LOC = "P8"  ; 
NET "D<14>"  LOC = "P9"  ; 
NET "D<15>"  LOC = "P10"  ; 
NET "DTACK_CPU_n"  LOC = "P13" | NOREDUCE = TRUE ;
NET "DTACK_MB_n"  LOC = "P14"  ; 
NET "E"  LOC = "P18"  ; 
NET "FC<0>"  LOC = "P35"  ; 
NET "FC<1>"  LOC = "P34"  ; 
NET "FC<2>"  LOC = "P33"  ; 
NET "IDE_CS_n<0>"  LOC = "P29"  ; 
NET "IDE_CS_n<1>"  LOC = "P30"  ; 
NET "IDE_IOR_n"  LOC = "P72"  ; 
NET "IDE_IOW_n"  LOC = "P73"  ; 
NET "JP2"  LOC = "P74"  ; 
NET "JP4"  LOC = "P67"  ;
NET "LDS_n"  LOC = "P81"  ; 
NET "OE_BANK0_n"  LOC = "P37"  ; 
NET "OE_BANK1_n"  LOC = "P11"  ; 
NET "RESET_n"  LOC = "P99" | BUFG = SR ; 
NET "ROM_OE_n"  LOC = "P71"  ; 
NET "RW_n"  LOC = "P82"  ; 
NET "SW1"  LOC = "P76"  ; 
NET "UDS_n"  LOC = "P80"  ; 
NET "VMA_n"  LOC = "P16"  ; 
NET "VPA_n"  LOC = "P15"  ; 
NET "WE_BANK0_EVEN_n"  LOC = "P50"  ; 
NET "WE_BANK0_ODD_n"  LOC = "P77"  ; 
NET "WE_BANK1_EVEN_n"  LOC = "P64"  ; 
NET "WE_BANK1_ODD_n"  LOC = "P97"  ; 

#PACE: Start of PACE Area Constraints

#PACE: Start of PACE Prohibit Constraints

#PACE: End of Constraints generated by PACE

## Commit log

2021-05-13 added schematic pdf
2021-05-24 Update schematic pdf
2021-05-31 allow for dma
2021-06-16 Removed unused pin assignments
2021-06-16 added rev1b schematic
2021-09-02 added KiCad files
    [SF500.kicad_pcb, SF500.sch, ide_and_eeprom.sch]
2021-12-22 implemented DMA support for other busmaster e.g. A590 on expansion edge
2022-01-13 fixed modified symbol 68000D to reside in SF500.lib
    [SF500.sch]
2022-02-04 Update BOM with CY62167ELL-45ZXI verified working

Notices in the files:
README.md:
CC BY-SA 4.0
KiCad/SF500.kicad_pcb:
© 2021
